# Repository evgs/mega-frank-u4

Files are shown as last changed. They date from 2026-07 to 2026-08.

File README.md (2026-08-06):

# MEGAFRANK 1.02-U4
MegaFRANK is a hardware emulation platform built around the Raspberry Pi RP2350 QFN module
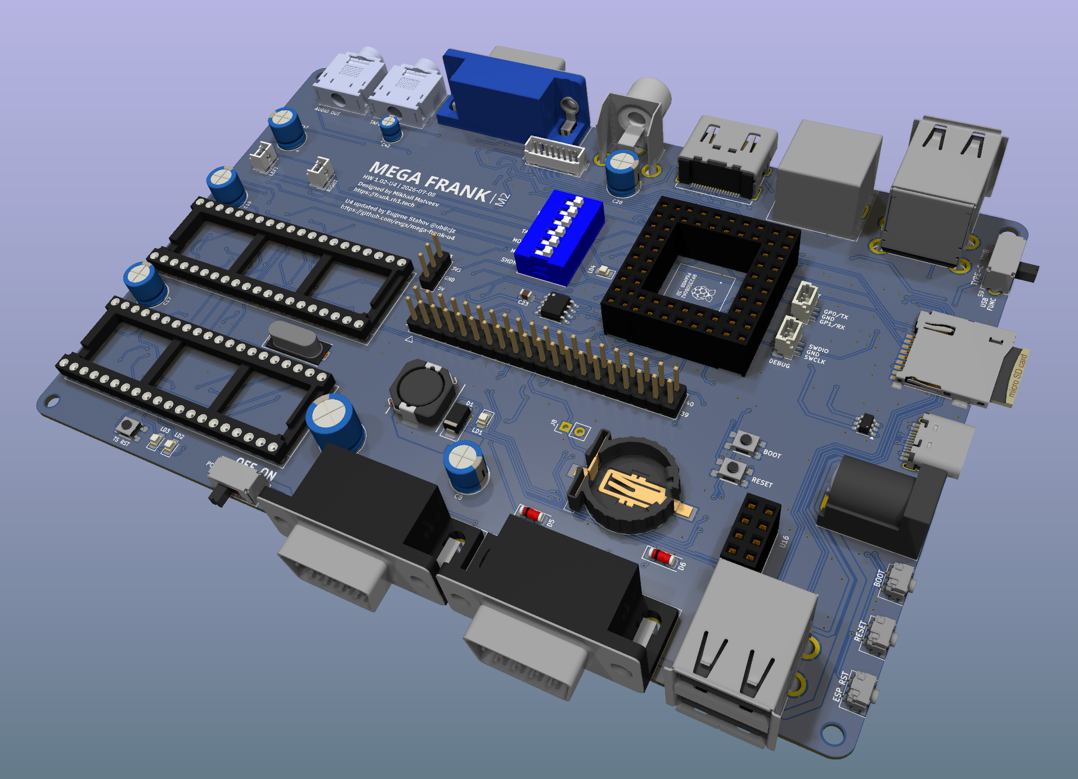
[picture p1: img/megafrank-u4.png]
board view


## DISCLAIMER 
This megafrank-u4 board is a sub-fork from https://github.com/rh1tech/frank repository originally designed by [Mikhail Matveev](https://github.com/xtremespb), [r1tech](https://github.com/rh1tech)

## Changes
- Two stacked USB-A ports were added on front board edge. 4 USB-A host ports total
- Power barrel 5mm connector was moved to right edge of the board
- ESP-RESET connected to PGPIO36 (optional, available if S11 jumper is closed) 

## DIP Switches S1 description
| Switch | Function |
| --- | --- |
| TDA | Sound path through I2S TDA (On) or PWM (Off) |
| TS | Enable TurboSound path (On) |
| TAPE | Connect TAPE IN analog input to RP2540B |
| MONO | Mono (On) of Stereo (Off) sound path |
| MPU | Enable +3V3 external pullup on GPIO0/1 (Mouse/UART port) |
| SHDN | Shutdown (On) speaker amplifier PAM8403 (outputs J13, J14) |

## TDA/TS switches useful combinations
| TDA | TS | Output selected |
| --- | --- | --- |
| off | off | RP2350 PWM |
| **ON** | off | I2S TDA1387T |
| off | **ON** | Turbosound 2xAY-3-8910 |
| **ON** | **ON** | Output Disabled |

Please read detailed docs in original project [FRANK repository](https://github.com/rh1tech/frank)

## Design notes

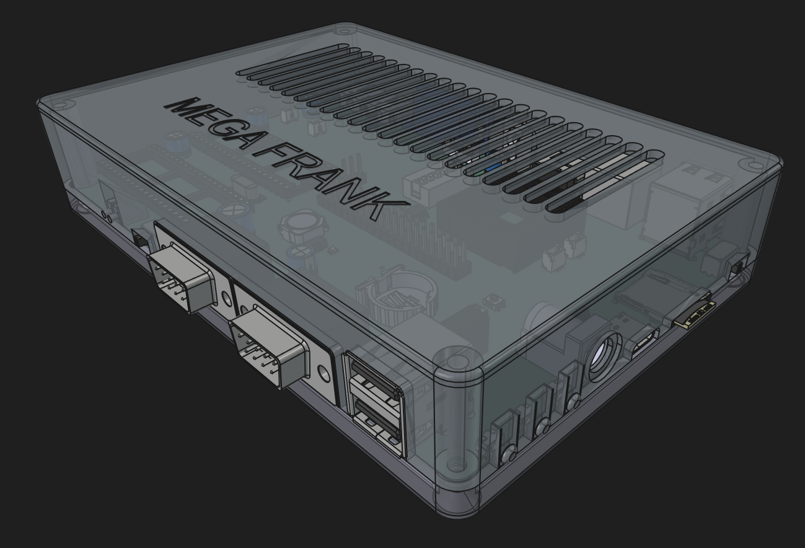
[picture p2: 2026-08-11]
case/case_preview.png

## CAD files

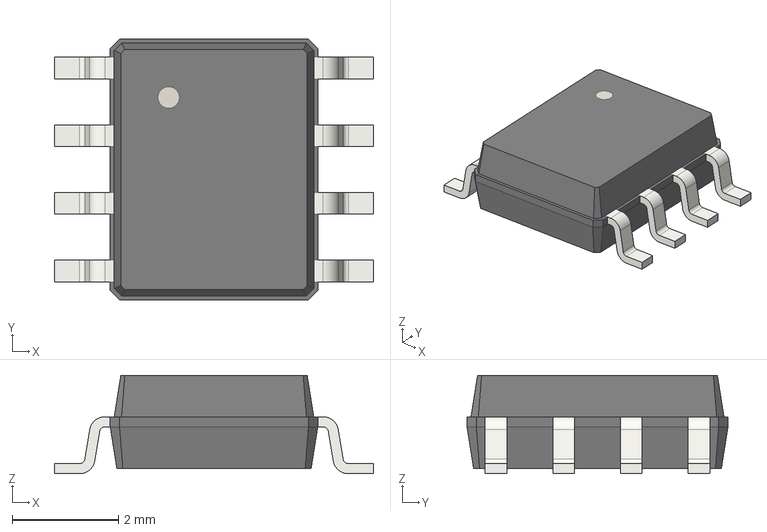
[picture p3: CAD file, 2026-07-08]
3d/SO-8.step
6.00 x 4.91 x 1.85 mm

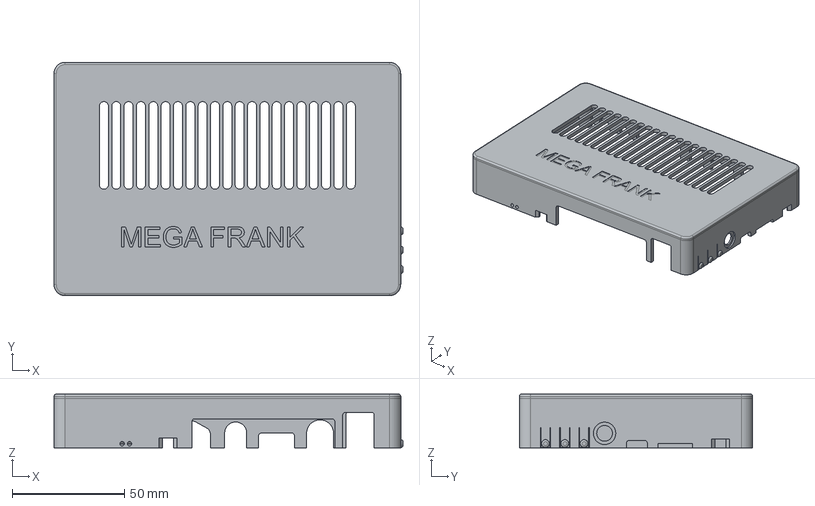
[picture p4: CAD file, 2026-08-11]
case/top-m2.5-inserts32.step
155.5 x 104.0 x 24.0 mm

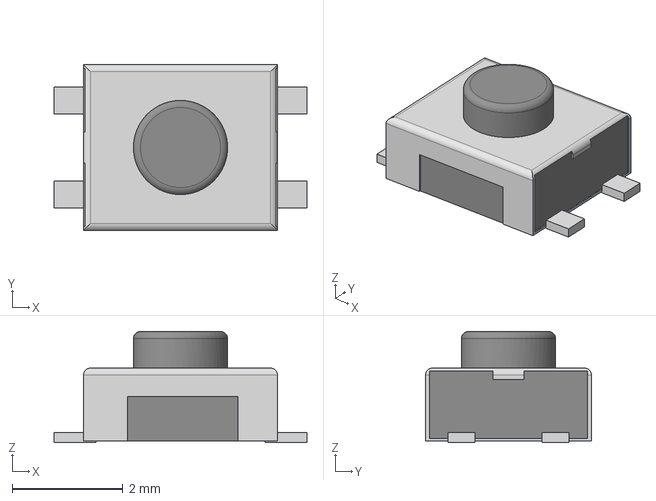
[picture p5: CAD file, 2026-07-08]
3d/Button_SMD_3x4x2mm.step
4.57 x 3.00 x 2.01 mm

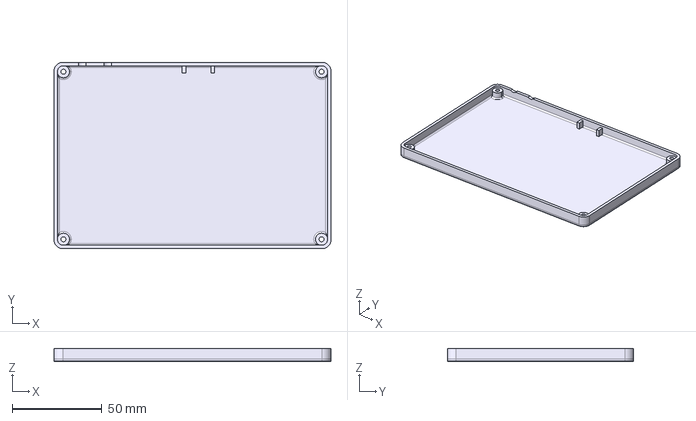
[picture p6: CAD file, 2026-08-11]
case/bottom.step
154.5 x 104.0 x 7.50 mm

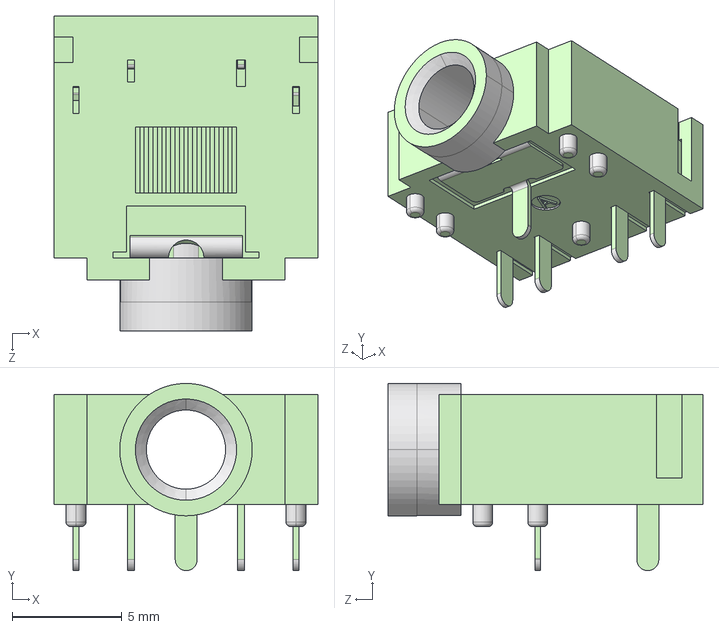
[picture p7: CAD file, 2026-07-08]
3d/AudioJack_3.5mm_SJ1-3525N_Green.step
12.0 x 8.51 x 14.3 mm

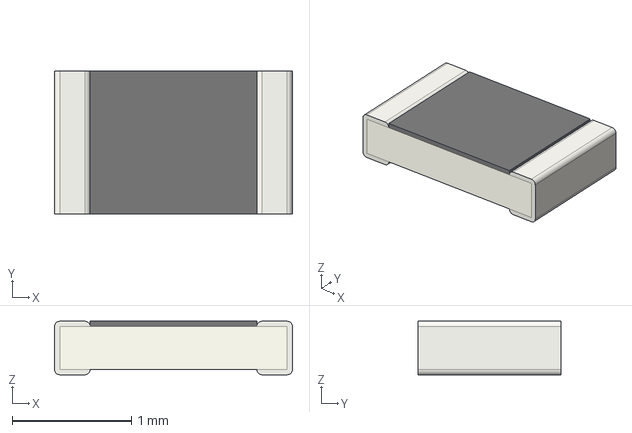
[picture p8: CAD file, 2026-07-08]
3d/R_0805_2012Metric.step
2.00 x 1.20 x 0.45 mm

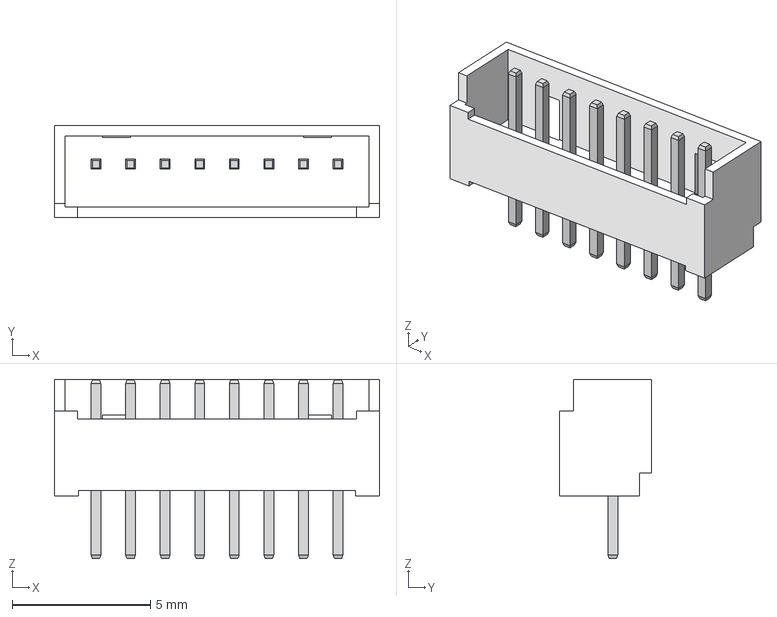
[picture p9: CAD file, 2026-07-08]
3d/JST_GH_1x08_P1.25mm.step
11.7 x 3.33 x 6.48 mm

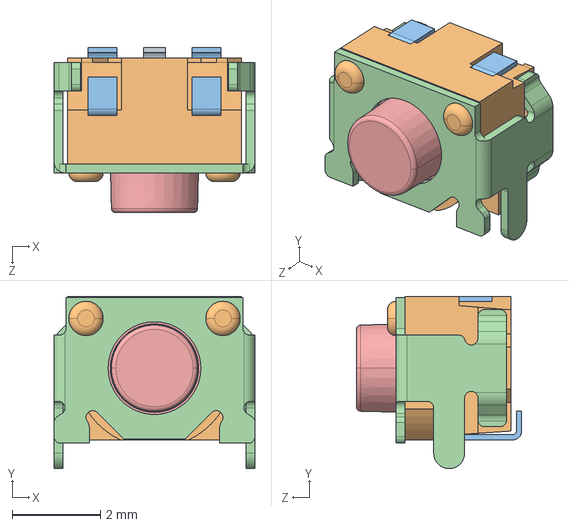
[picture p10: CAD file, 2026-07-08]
3d/Button_SMD_TS1234VW.step
4.55 x 3.90 x 3.74 mm
TS41_HOUSING
TS41-35_ACTUATOR

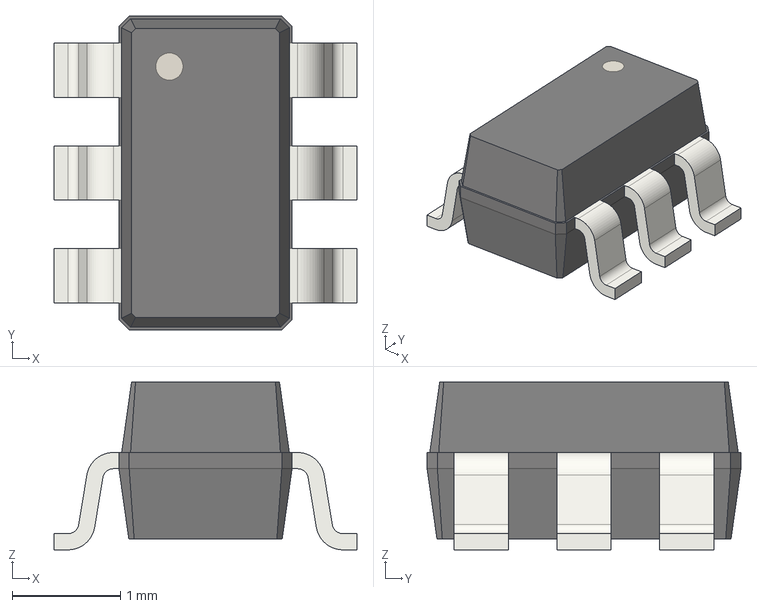
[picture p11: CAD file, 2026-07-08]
3d/SOT-23-6.step
2.80 x 2.90 x 1.55 mm

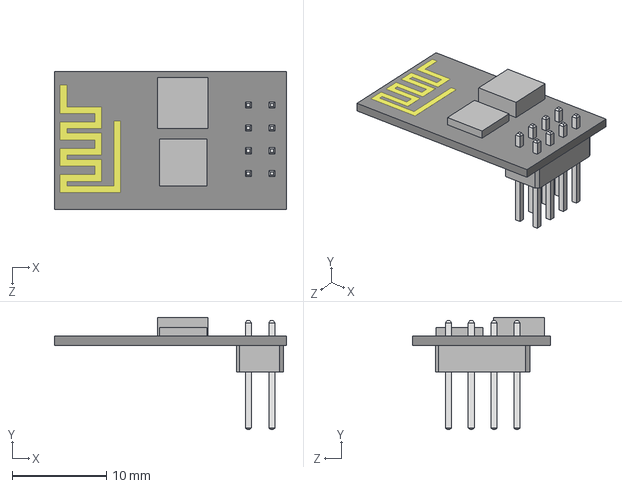
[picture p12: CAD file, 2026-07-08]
3d/ESP-01S.step
24.6 x 11.9 x 14.7 mm

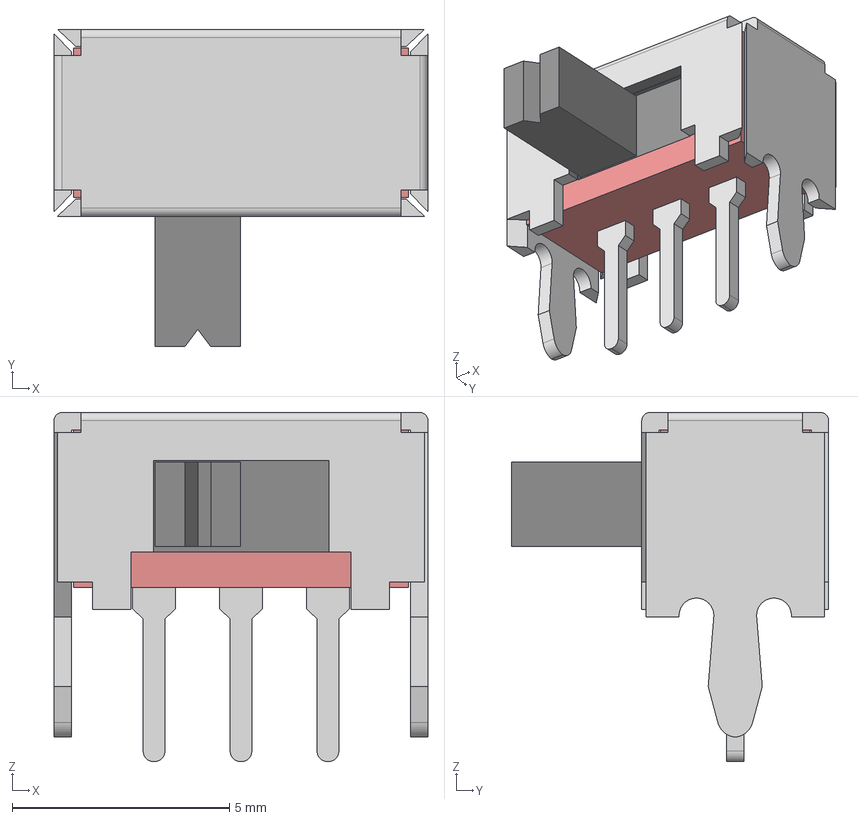
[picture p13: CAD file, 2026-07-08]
3d/Switch_Slide_SK12D07VG3NS.step
8.60 x 7.30 x 8.03 mm

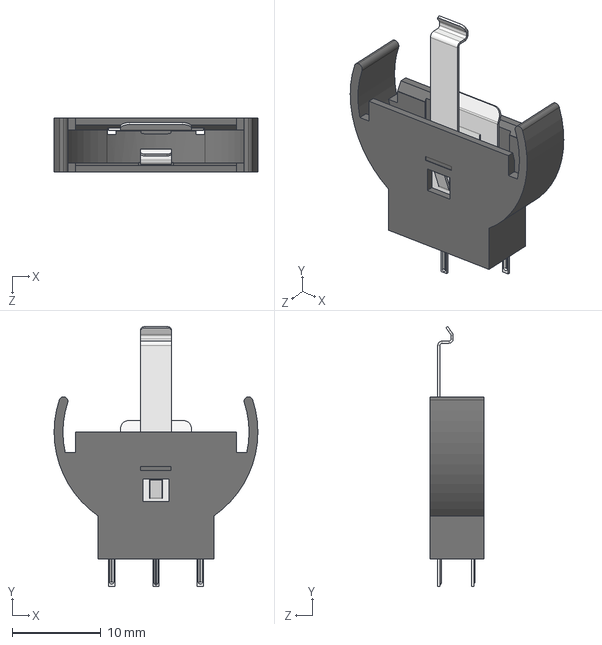
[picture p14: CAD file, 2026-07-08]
3d/Battery_CR2032.step
23.0 x 29.3 x 6.10 mm

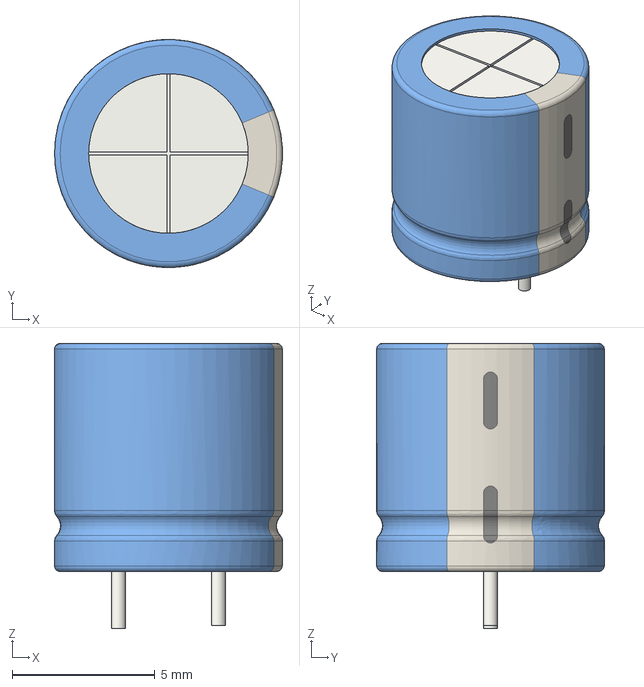
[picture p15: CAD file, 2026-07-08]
3d/C_Radial_D8.0mm_P3.50mm.step
8.00 x 8.00 x 10.0 mm

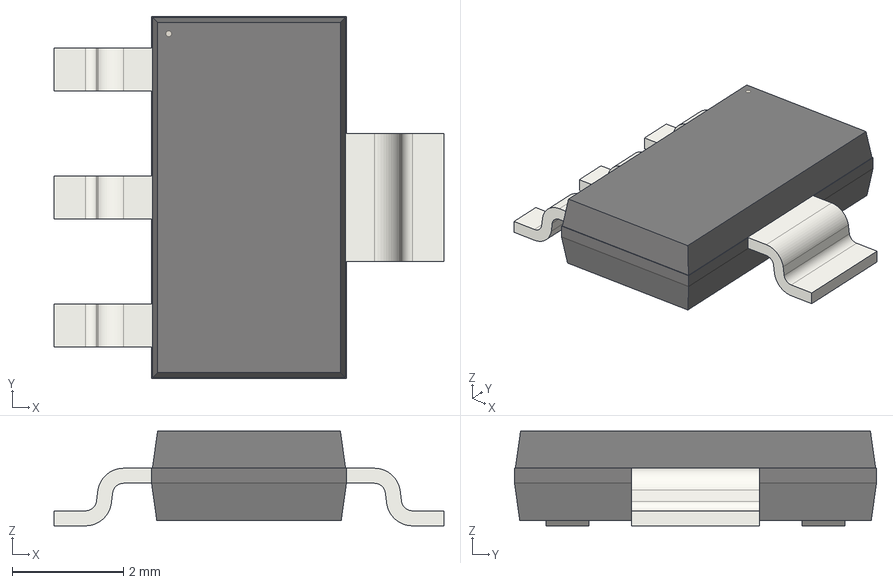
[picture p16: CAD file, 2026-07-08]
3d/SOT-223-3_TabPin2.step
7.00 x 6.50 x 1.70 mm

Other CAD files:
3d/JST_GH_1x02_P1.25mm.step
3d/AudioJack_3.5mm_SJ1-3525N_Red.step
3d/DIPSwitch_4pos_DS05.step
3d/C_0805_2012Metric.step
3d/AudioJack_3.5mm_PJ320D.step
3d/AudioJack_3.5mm_PJ320D_AudioOut.step
3d/AudioJack_3.5mm_PJ320D_TapeIn.step
3d/AudioJack_3.5mm_SJ1-3525N.step
3d/BAT-HLD-013-SMT-TR.step
3d/BarrelJack_DC-005.step
3d/BarrelJack_RCJ-012.step
3d/Battery_CR1220.step
3d/CP_Radial_D4.0mm_P1.50mm.step
3d/C_Radial_D6.3mm_P2.50mm.step
3d/Crystal_HC49-S.step
3d/DIP-40_W15.24mm_Socket.step
3d/DS01-254-S-06BE.step
3d/DS2401P+.stp
3d/DSUB-15_Female.step
3d/DSUB-9_Male_TopMount.step
3d/D_MiniMELF.step
3d/D_SMA.step
3d/D_SOD-323.step
3d/HDMI_Female.step
3d/Inductor_CDRH104RNP.step
3d/JST_SH_1x03_P1.00mm_Vertical.step
3d/JST_SH_1x04_P1.00mm_Vertical.step
3d/LED_0805.step
3d/MicroSD_SMD_Long.step
3d/MiniDIN_6pin_Female.step
3d/PinHeader_1x03_P2.54mm.step
3d/PinHeader_2x04_P2.54mm.step
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

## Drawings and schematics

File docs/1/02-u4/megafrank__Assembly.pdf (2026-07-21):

1 | 2 | 3 | 4 | 5 | 6 1 | 2 | 3 | 4 | 5 | 6 ABCD | ABCD Date: 2026-07-08

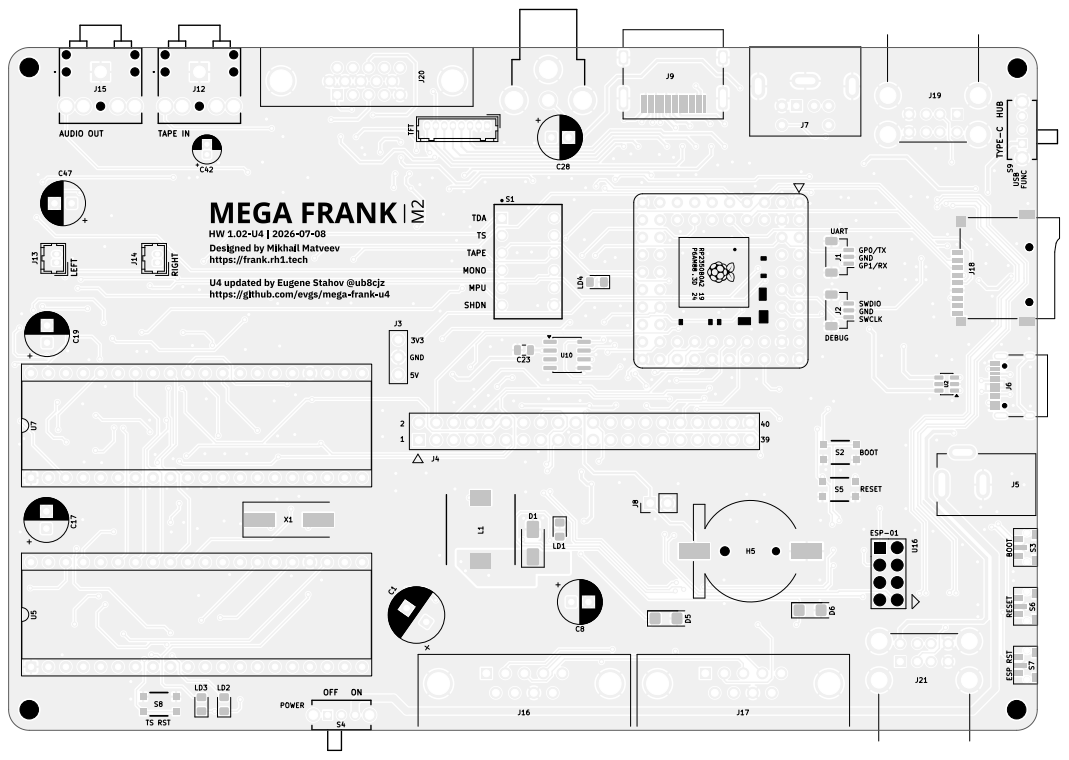
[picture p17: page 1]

Black And White TOP - Page 1/2

https://github.com/rh1tech/frank
Mikhail Matveev
Sheet: Black And White TOP
File: megafrank.kicad_pcb
Title: MEGA FRANK
KiCad E.D.A. 10.0.4

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

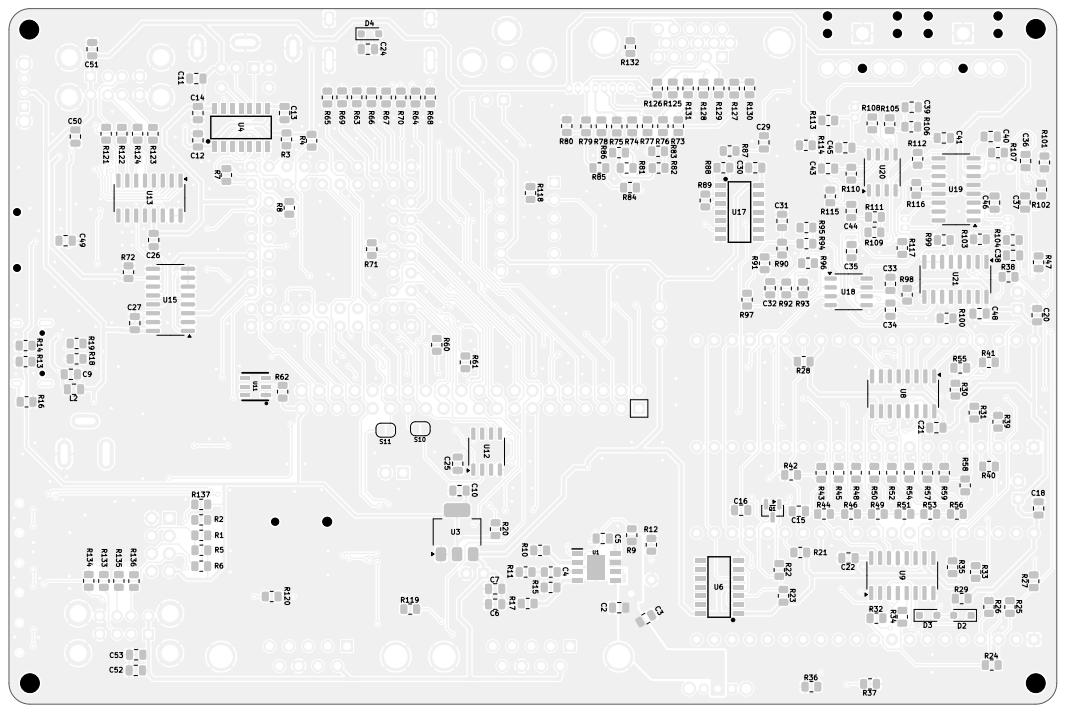
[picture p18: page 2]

https://github.com/rh1tech/frank
Mikhail Matveev
Sheet: Black And White BOT
File: megafrank.kicad_pcb
Title: MEGA FRANK

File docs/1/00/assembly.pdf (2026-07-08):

1 | 2 | 3 | 4 | 5 | 6 1 | 2 | 3 | 4 | 5 | 6 ABCD | ABCD Date: 2026-05-31

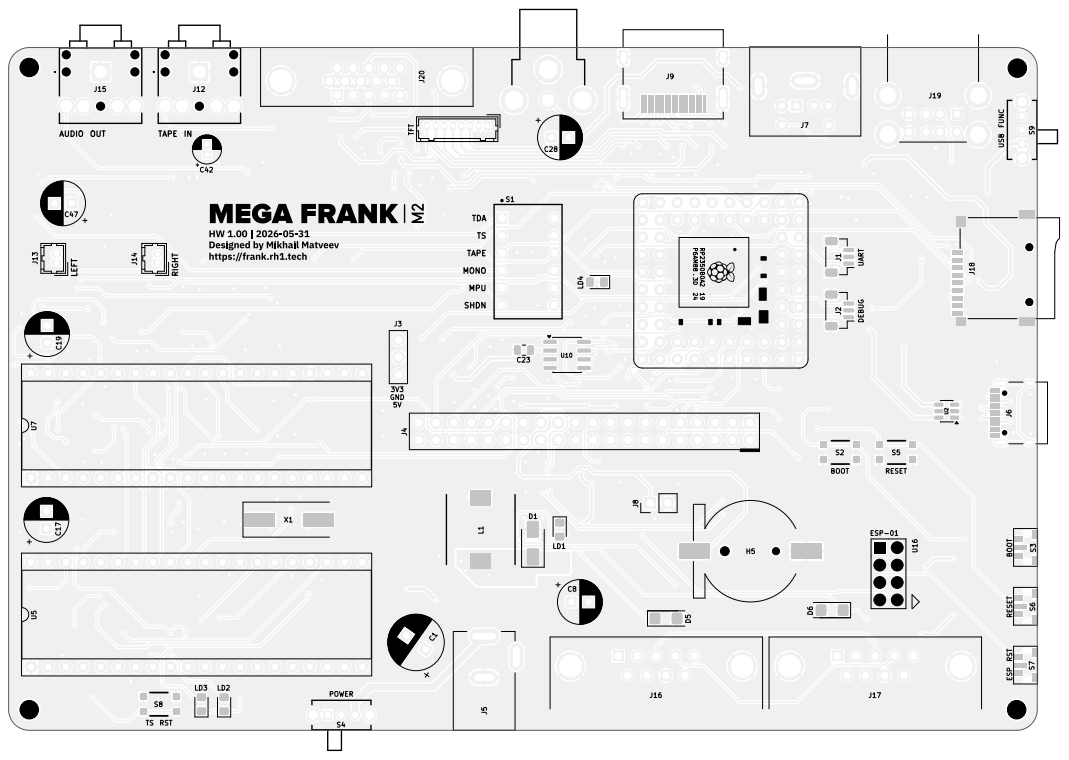
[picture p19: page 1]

Black And White TOP - Page 1/2

https://github.com/rh1tech/frank
Mikhail Matveev
Sheet: Black And White TOP
File: frank_mega.kicad_pcb
Title: MEGA FRANK
KiCad E.D.A. 10.0.1

1 | 2 | 3 | 4 | 5 | 6 1 | 2 | 3 | 4 | 5 | 6 ABCD | ABCD Date: 2026-05-31
U1 C24

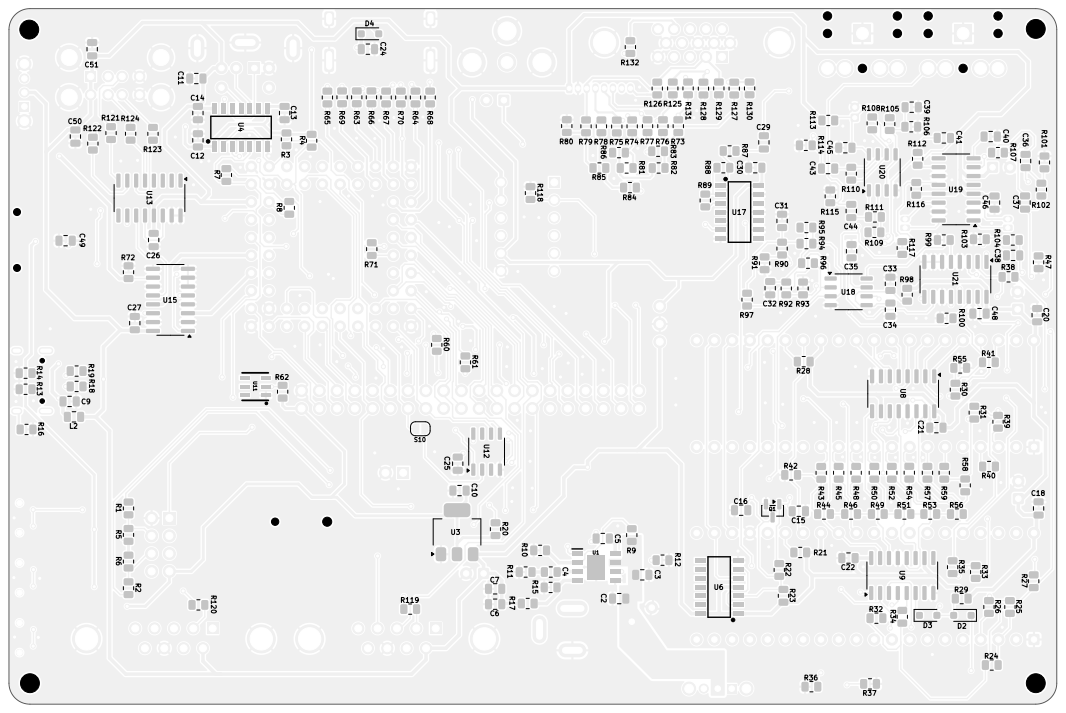
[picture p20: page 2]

https://github.com/rh1tech/frank
Mikhail Matveev
Sheet: Black And White BOT
File: frank_mega.kicad_pcb
Title: MEGA FRANK
KiCad E.D.A. 10.0.1

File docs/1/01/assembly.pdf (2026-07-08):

1 | 2 | 3 | 4 | 5 | 6 1 | 2 | 3 | 4 | 5 | 6 ABCD | ABCD Date: 2026-06-04

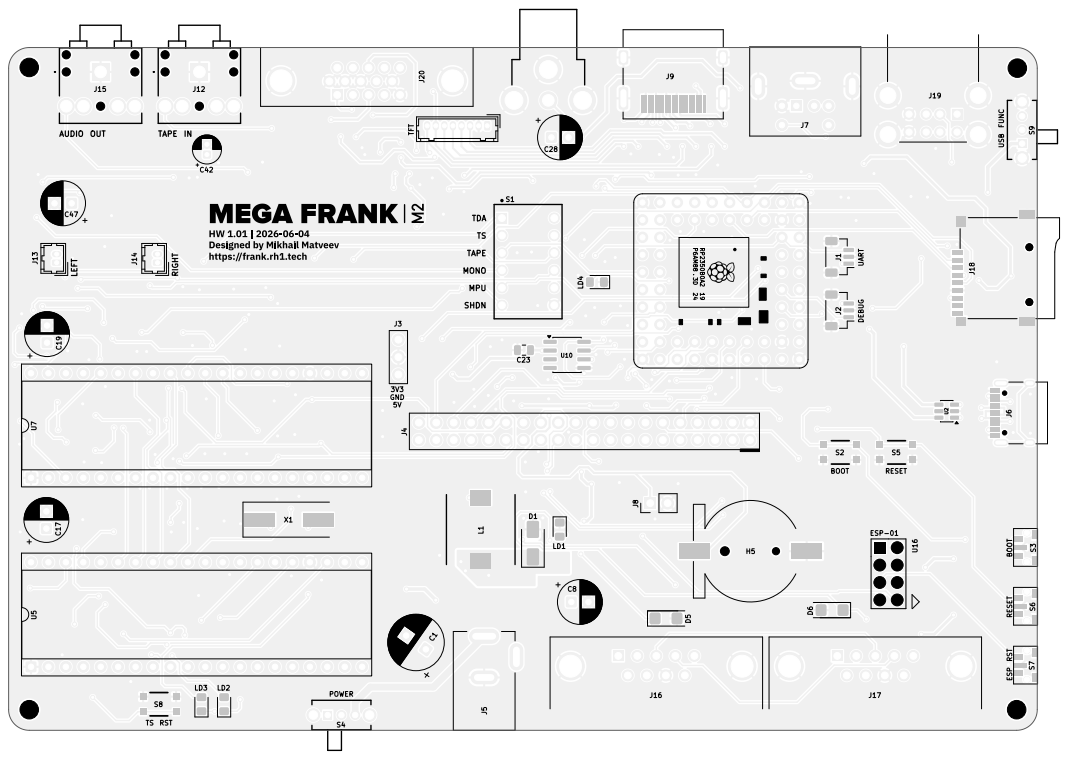
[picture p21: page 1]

Black And White TOP - Page 1/2

https://github.com/rh1tech/frank
Mikhail Matveev
Sheet: Black And White TOP
File: frank_mega.kicad_pcb
Title: MEGA FRANK
KiCad E.D.A. 10.0.1

1 | 2 | 3 | 4 | 5 | 6 1 | 2 | 3 | 4 | 5 | 6 ABCD | ABCD Date: 2026-06-04
U1 C24

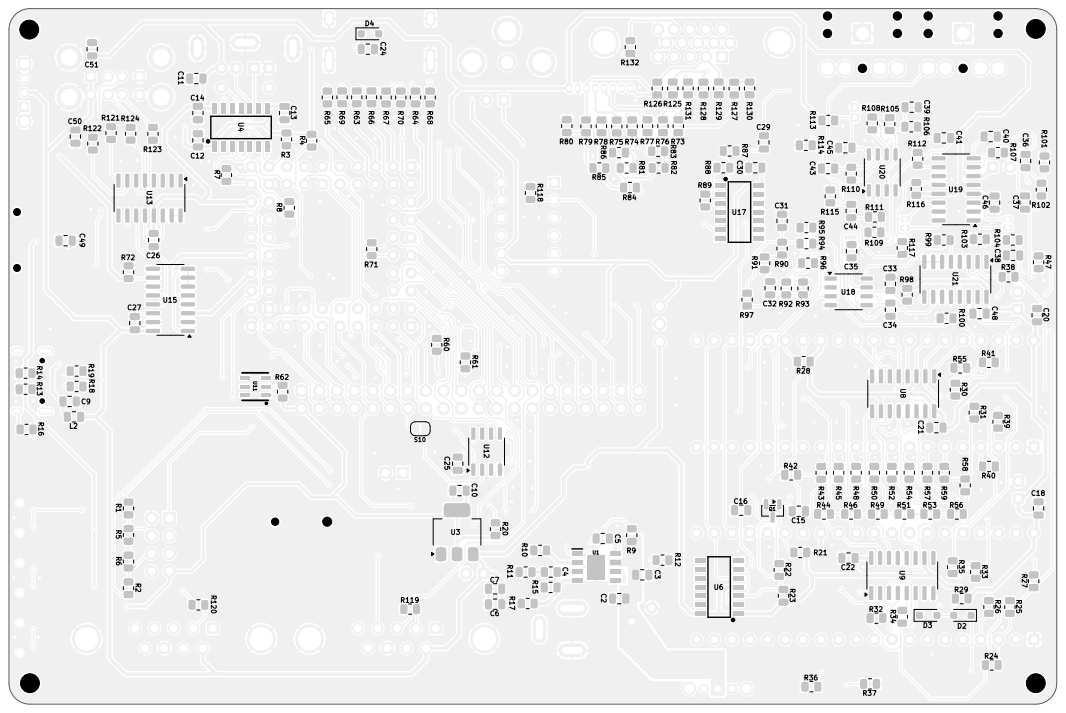
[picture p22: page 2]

https://github.com/rh1tech/frank
Mikhail Matveev
Sheet: Black And White BOT
File: frank_mega.kicad_pcb
Title: MEGA FRANK
KiCad E.D.A. 10.0.1

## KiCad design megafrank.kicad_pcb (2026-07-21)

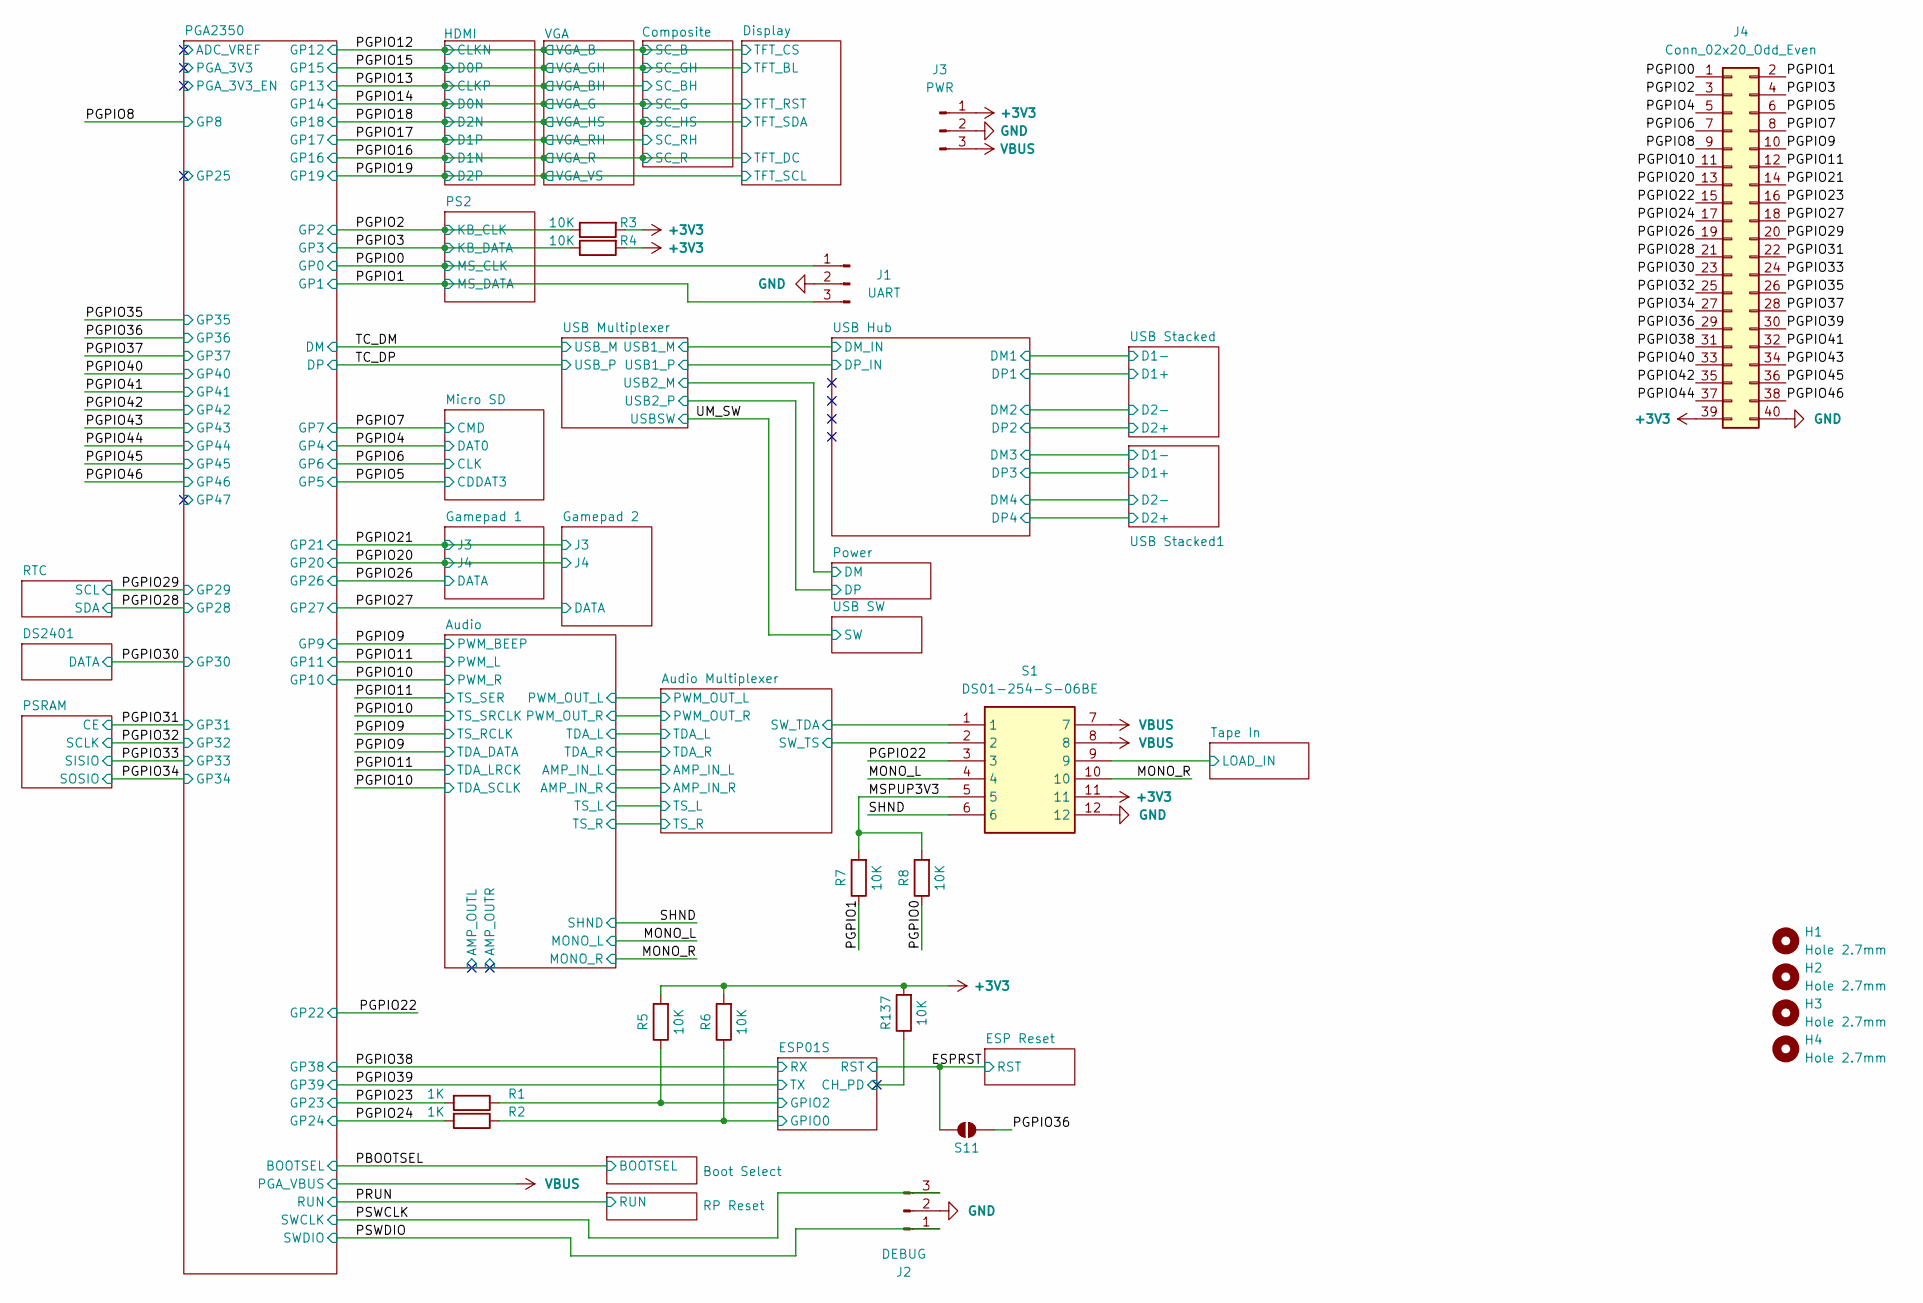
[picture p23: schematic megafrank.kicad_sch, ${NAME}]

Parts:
H1, H2, H3, H4: Hole 2.7mm; MountingHole_2.7mm
J1: UART; JST_SH_1x03_P1.00mm_Vertical
J2: DEBUG; JST_SH_1x03_P1.00mm_Vertical
J3: PWR; PinHeader_1x03_P2.54mm
J4: Conn_02x20_Odd_Even; PinHeader_2x20_P2.54mm_Vertical
R1, R2: 1K; R_0805_2012Metric
R3, R4, R5, R6, R7, R8, R137: 10K; R_0805_2012Metric
S1: DS01-254-S-06BE; Manufacturer_Part_Number DS01-254-S-06BE
S11: PICO-ESP-RESET; SolderJumper-2_P1.3mm_Open_RoundedPad1.0x1.5mm

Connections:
+3V3: J3.1, J4.39, R3.2, R4.2, R5.2, R6.2, R137.2, S1.11; also elsewhere on the board
/Audio Multiplexer/SW_TDA: S1.1; also elsewhere on the board
/Audio Multiplexer/SW_TS: S1.2; also elsewhere on the board
/ESP01S/CH_PD: R137.1; also elsewhere on the board
/ESP01S/GPIO0: R2.1, R6.1; also elsewhere on the board
/ESP01S/GPIO2: R1.1, R5.1; also elsewhere on the board
/ESPRST: S11.1 (A); also elsewhere on the board
/MONO_L: S1.4; also elsewhere on the board
/MONO_R: S1.10; also elsewhere on the board
/MSPUP3V3: R7.2, R8.2, S1.5
/PGPIO0: J1.1, J4.1, R8.1; also elsewhere on the board
/PGPIO1: J1.3, J4.2, R7.1; also elsewhere on the board
/PGPIO2: J4.3, R3.1; also elsewhere on the board
/PGPIO3: J4.4, R4.1; also elsewhere on the board
/PGPIO4: J4.5; also elsewhere on the board
/PGPIO5: J4.6; also elsewhere on the board
/PGPIO6: J4.7; also elsewhere on the board
/PGPIO7: J4.8; also elsewhere on the board
/PGPIO8: J4.9; also elsewhere on the board
/PGPIO9: J4.10; also elsewhere on the board
/PGPIO10: J4.11; also elsewhere on the board
/PGPIO11: J4.12; also elsewhere on the board
/PGPIO20: J4.13; also elsewhere on the board
/PGPIO21: J4.14; also elsewhere on the board
/PGPIO22: J4.15, S1.3; also elsewhere on the board
/PGPIO23: J4.16, R1.2; also elsewhere on the board
/PGPIO24: J4.17, R2.2; also elsewhere on the board
/PGPIO26: J4.19; also elsewhere on the board
/PGPIO27: J4.18; also elsewhere on the board
/PGPIO28: J4.21; also elsewhere on the board
/PGPIO29: J4.20; also elsewhere on the board
/PGPIO30: J4.23; also elsewhere on the board
/PGPIO31: J4.22; also elsewhere on the board
/PGPIO32: J4.25; also elsewhere on the board
/PGPIO33: J4.24; also elsewhere on the board
/PGPIO34: J4.27; also elsewhere on the board
/PGPIO35: J4.26; also elsewhere on the board
/PGPIO36: J4.29, S11.2 (B); also elsewhere on the board
/PGPIO37: J4.28; also elsewhere on the board
/PGPIO38: J4.31; also elsewhere on the board
/PGPIO39: J4.30; also elsewhere on the board
/PGPIO40: J4.33; also elsewhere on the board
/PGPIO41: J4.32; also elsewhere on the board
/PGPIO42: J4.35; also elsewhere on the board
/PGPIO43: J4.34; also elsewhere on the board
/PGPIO44: J4.37; also elsewhere on the board
/PGPIO45: J4.36; also elsewhere on the board
/PGPIO46: J4.38; also elsewhere on the board
/PSWCLK: J2.3; also elsewhere on the board
/PSWDIO: J2.1; also elsewhere on the board
/SHND: S1.6; also elsewhere on the board
/Tape In/LOAD_IN: S1.9; also elsewhere on the board
GND: J1.2, J2.2, J3.2, J4.40, S1.12; also elsewhere on the board
VBUS: J3.3, S1.7, S1.8; also elsewhere on the board

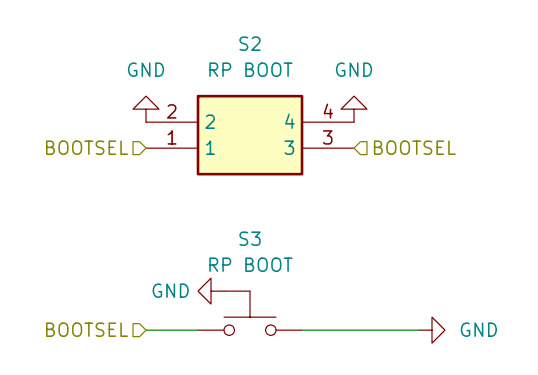
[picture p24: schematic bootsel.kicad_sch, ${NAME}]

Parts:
S2: RP BOOT; Button_SMD_3x4x2mm; Mouser Part Number 611-KMR221G-LFS
S3: RP BOOT; Button_SMD_TS1234VW

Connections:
/PBOOTSEL: S2.1, S2.3, S3.1; also elsewhere on the board
GND: S2.2, S2.4, S3.2, S3.3 (GND); also elsewhere on the board

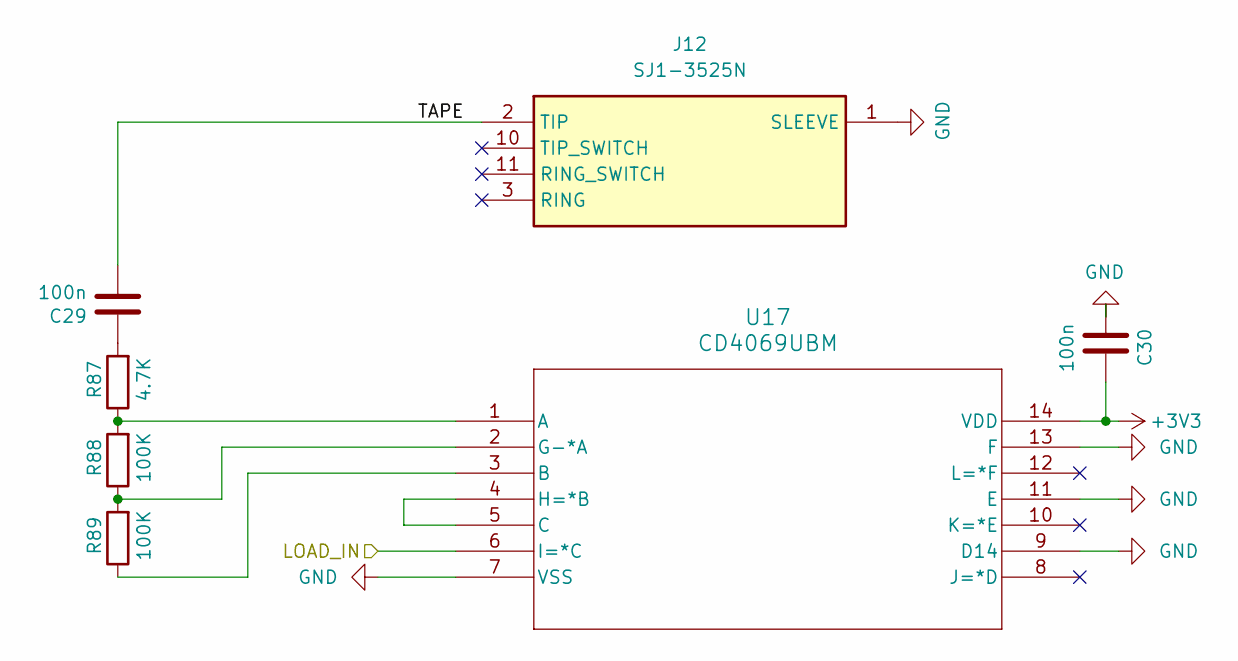
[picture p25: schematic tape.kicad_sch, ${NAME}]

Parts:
C29, C30: 100n; C_0805_2012Metric
J12: SJ1-3525N; AudioJack_3.5mm_SJ1-3525N; Mouser Part Number 490-SJ1-3525N
R87: 4.7K; R_0805_2012Metric
R88, R89: 100K; R_0805_2012Metric
U17: CD4069UBM; SOIC-14_P1.27mm

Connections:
+3V3: C30.1, U17.14 (VDD); also elsewhere on the board
/Tape In/LOAD_IN: U17.6 (I=*C); also elsewhere on the board
/Tape In/TAPE: C29.2, J12.2 (TIP)
GND: C30.2, J12.1 (SLEEVE), U17.7 (VSS), U17.9 (D14), U17.11 (E), U17.13 (F); also elsewhere on the board
unnamed: C29.1, R87.2
unnamed: R87.1, R88.2, U17.1 (A)
unnamed: R89.1, U17.3 (B)
unnamed: U17.4 (H=*B), U17.5 (C)
unnamed: R88.1, R89.2, U17.2 (G-*A)

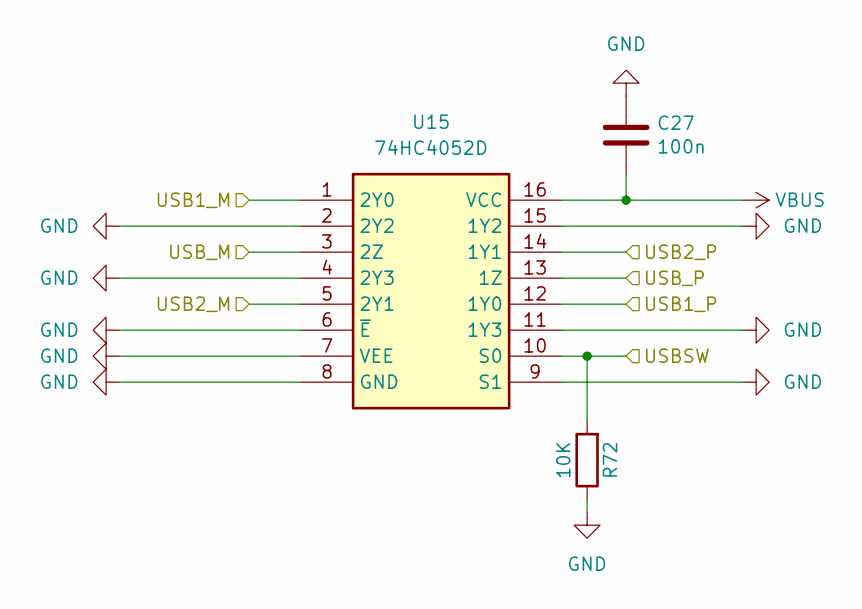
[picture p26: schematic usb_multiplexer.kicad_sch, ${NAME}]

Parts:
C27: 100n; C_0805_2012Metric
R72: 10K; R_0805_2012Metric
U15: 74HC4052D; SOP-16_P1.27mm; Mouser Part Number 771-74HC4052D-T

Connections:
/Power/DM: U15.5 (2Y1); also elsewhere on the board
/Power/DP: U15.14 (1Y1); also elsewhere on the board
/TC_DM: U15.3 (2Z); also elsewhere on the board
/TC_DP: U15.13 (1Z); also elsewhere on the board
/UM_SW: R72.2, U15.10 (S0); also elsewhere on the board
/USB Hub/DM_IN: U15.1 (2Y0); also elsewhere on the board
/USB Hub/DP_IN: U15.12 (1Y0); also elsewhere on the board
GND: C27.1, R72.1, U15.2 (2Y2), U15.4 (2Y3), U15.6 (~E), U15.7 (VEE), U15.8 (GND), U15.9 (S1), U15.11 (1Y3), U15.15 (1Y2); also elsewhere on the board
VBUS: C27.2, U15.16 (VCC); also elsewhere on the board

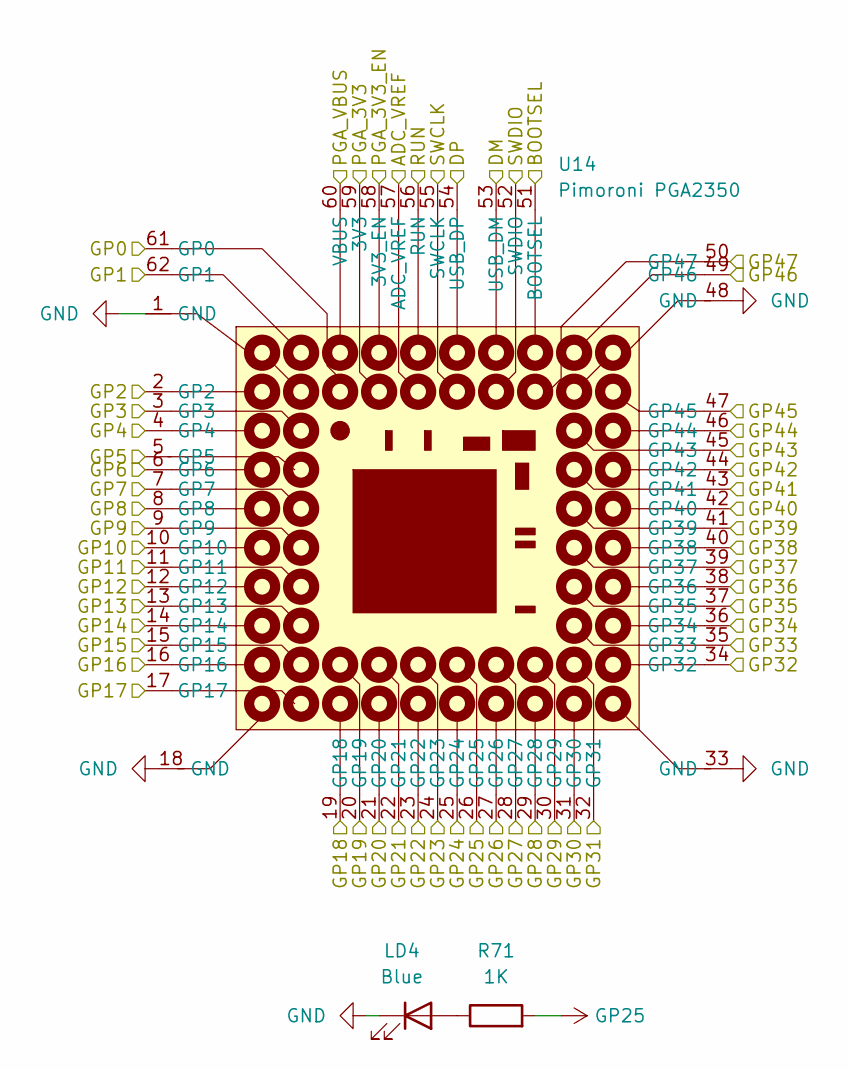
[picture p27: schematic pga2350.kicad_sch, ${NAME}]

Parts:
LD4: Blue; LED_0805
R71: 1K; R_0805_2012Metric
U14: Pimoroni PGA2350; PGA2350

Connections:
/PBOOTSEL: U14.51 (BOOTSEL); also elsewhere on the board
/PGA2350/ADC_VREF: U14.57 (ADC_VREF)
/PGA2350/GP47: U14.50 (GP47)
/PGA2350/PGA_3V3: U14.59 (3V3)
/PGA2350/PGA_3V3_EN: U14.58 (3V3_EN)
/PGPIO0: U14.61 (GP0); also elsewhere on the board
/PGPIO1: U14.62 (GP1); also elsewhere on the board
/PGPIO2: U14.2 (GP2); also elsewhere on the board
/PGPIO3: U14.3 (GP3); also elsewhere on the board
/PGPIO4: U14.4 (GP4); also elsewhere on the board
/PGPIO5: U14.5 (GP5); also elsewhere on the board
/PGPIO6: U14.6 (GP6); also elsewhere on the board
/PGPIO7: U14.7 (GP7); also elsewhere on the board
/PGPIO8: U14.8 (GP8); also elsewhere on the board
/PGPIO9: U14.9 (GP9); also elsewhere on the board
/PGPIO10: U14.10 (GP10); also elsewhere on the board
/PGPIO11: U14.11 (GP11); also elsewhere on the board
/PGPIO12: U14.12 (GP12); also elsewhere on the board
/PGPIO13: U14.13 (GP13); also elsewhere on the board
/PGPIO14: U14.14 (GP14); also elsewhere on the board
/PGPIO15: U14.15 (GP15); also elsewhere on the board
/PGPIO16: U14.16 (GP16); also elsewhere on the board
/PGPIO17: U14.17 (GP17); also elsewhere on the board
/PGPIO18: U14.19 (GP18); also elsewhere on the board
/PGPIO19: U14.20 (GP19); also elsewhere on the board
/PGPIO20: U14.21 (GP20); also elsewhere on the board
/PGPIO21: U14.22 (GP21); also elsewhere on the board
/PGPIO22: U14.23 (GP22); also elsewhere on the board
/PGPIO23: U14.24 (GP23); also elsewhere on the board
/PGPIO24: U14.25 (GP24); also elsewhere on the board
/PGPIO26: U14.27 (GP26); also elsewhere on the board
/PGPIO27: U14.28 (GP27); also elsewhere on the board
/PGPIO28: U14.29 (GP28); also elsewhere on the board
/PGPIO29: U14.30 (GP29); also elsewhere on the board
/PGPIO30: U14.31 (GP30); also elsewhere on the board
/PGPIO31: U14.32 (GP31); also elsewhere on the board
/PGPIO32: U14.34 (GP32); also elsewhere on the board
/PGPIO33: U14.35 (GP33); also elsewhere on the board
/PGPIO34: U14.36 (GP34); also elsewhere on the board
/PGPIO35: U14.37 (GP35); also elsewhere on the board
/PGPIO36: U14.38 (GP36); also elsewhere on the board
/PGPIO37: U14.39 (GP37); also elsewhere on the board
/PGPIO38: U14.40 (GP38); also elsewhere on the board
/PGPIO39: U14.41 (GP39); also elsewhere on the board
/PGPIO40: U14.42 (GP40); also elsewhere on the board
/PGPIO41: U14.43 (GP41); also elsewhere on the board
/PGPIO42: U14.44 (GP42); also elsewhere on the board
/PGPIO43: U14.45 (GP43); also elsewhere on the board
/PGPIO44: U14.46 (GP44); also elsewhere on the board
/PGPIO45: U14.47 (GP45); also elsewhere on the board
/PGPIO46: U14.49 (GP46); also elsewhere on the board
/PRUN: U14.56 (RUN); also elsewhere on the board
/PSWCLK: U14.55 (SWCLK); also elsewhere on the board
/PSWDIO: U14.52 (SWDIO); also elsewhere on the board
/TC_DM: U14.53 (USB_DM); also elsewhere on the board
/TC_DP: U14.54 (USB_DP); also elsewhere on the board
GND: LD4.1 (K), U14.1 (GND), U14.18 (GND), U14.33 (GND), U14.48 (GND); also elsewhere on the board
GP25: R71.2, U14.26 (GP25)
unnamed: LD4.2 (A), R71.1
VBUS: U14.60 (VBUS); also elsewhere on the board

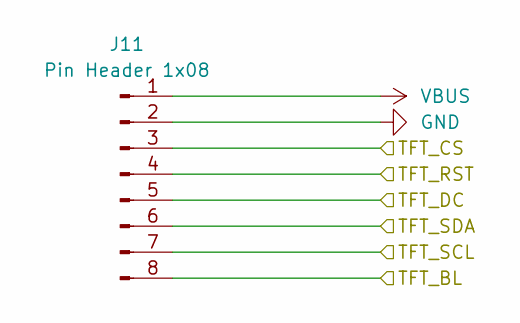
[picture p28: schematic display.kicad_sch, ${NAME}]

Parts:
J11: Pin Header 1x08; JST_GH_1x08_P1.25mm

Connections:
/PGPIO12: J11.3; also elsewhere on the board
/PGPIO14: J11.4; also elsewhere on the board
/PGPIO15: J11.8; also elsewhere on the board
/PGPIO16: J11.5; also elsewhere on the board
/PGPIO18: J11.6; also elsewhere on the board
/PGPIO19: J11.7; also elsewhere on the board
GND: J11.2; also elsewhere on the board
VBUS: J11.1; also elsewhere on the board

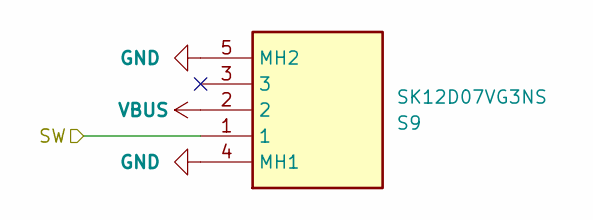
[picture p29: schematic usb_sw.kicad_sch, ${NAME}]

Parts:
S9: SK12D07VG3NS; Switch_Slide_SK12D07VG3NS; Mouser Part Number 611-SK12D07VG3NS

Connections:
/UM_SW: S9.1; also elsewhere on the board
GND: S9.4 (MH1), S9.5 (MH2); also elsewhere on the board
VBUS: S9.2; also elsewhere on the board

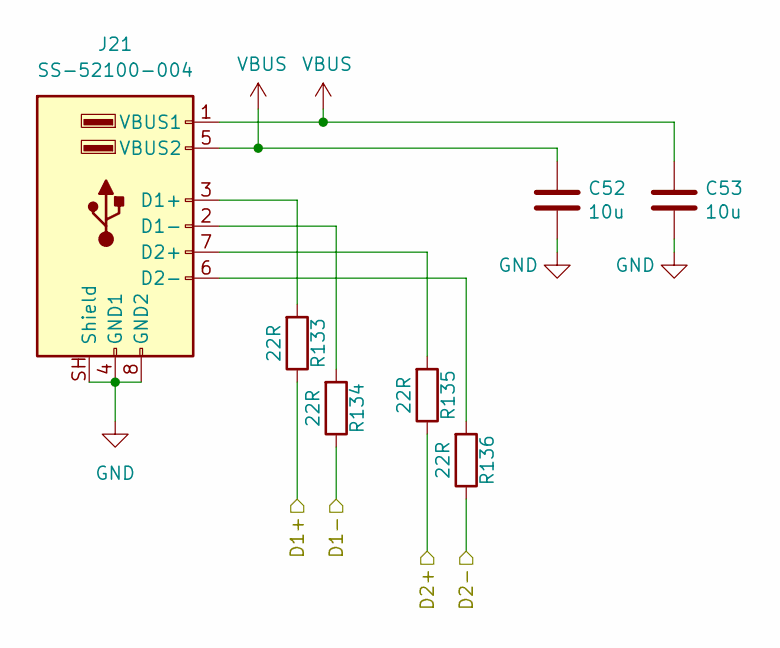
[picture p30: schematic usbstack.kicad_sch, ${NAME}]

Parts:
C52, C53: 10u; C_0805_2012Metric
J21: SS-52100-004; USB_A_Stacked
R133, R134, R135, R136: 22R; R_0805_2012Metric

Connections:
/USB Hub/DM3: R134.1; also elsewhere on the board
/USB Hub/DM4: R136.1; also elsewhere on the board
/USB Hub/DP3: R133.1; also elsewhere on the board
/USB Hub/DP4: R135.1; also elsewhere on the board
GND: C52.2, C53.2, J21.4 (GND1), J21.8 (GND2), J21.SH (Shield); also elsewhere on the board
unnamed: J21.3 (D1+), R133.2
unnamed: J21.2 (D1-), R134.2
unnamed: J21.7 (D2+), R135.2
unnamed: J21.6 (D2-), R136.2
VBUS: C52.1, C53.1, J21.1 (VBUS1), J21.5 (VBUS2); also elsewhere on the board

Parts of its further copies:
C50, C51: 10u; C_0805_2012Metric
J19: SS-52100-004; USB_A_Stacked
R121, R122, R123, R124: 22R; R_0805_2012Metric

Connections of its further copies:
/USB Hub/DM1: R122.1; also elsewhere on the board
/USB Hub/DM2: R124.1; also elsewhere on the board
/USB Hub/DP1: R121.1; also elsewhere on the board
/USB Hub/DP2: R123.1; also elsewhere on the board
GND: C50.2, C51.2, J19.4 (GND1), J19.8 (GND2), J19.SH (Shield); also elsewhere on the board
unnamed: J19.3 (D1+), R121.2
unnamed: J19.2 (D1-), R122.2
unnamed: J19.7 (D2+), R123.2
unnamed: J19.6 (D2-), R124.2
VBUS: C50.1, C51.1, J19.1 (VBUS1), J19.5 (VBUS2); also elsewhere on the board

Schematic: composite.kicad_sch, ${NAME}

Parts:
C28: 220u; C_Radial_D6.3mm_P2.50mm
J10: RCA-103; BarrelJack_RCJ-012
R73: 750R; R_0805_2012Metric
R74, R75, R76, R77, R78, R79: 270R; R_0805_2012Metric
R80: 300R; R_0805_2012Metric
R81, R82, R83, R84, R85: 150R; R_0805_2012Metric
R86: 51R; R_0805_2012Metric

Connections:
/Composite/CVBS: C28.2, J10.1
/PGPIO12: R79.1; also elsewhere on the board
/PGPIO13: R78.1; also elsewhere on the board
/PGPIO14: R75.1; also elsewhere on the board
/PGPIO15: R74.1; also elsewhere on the board
/PGPIO16: R77.1; also elsewhere on the board
/PGPIO17: R76.1; also elsewhere on the board
/PGPIO18: R73.1; also elsewhere on the board
GND: J10.2, R80.1; also elsewhere on the board
unnamed: C28.1, R86.2
unnamed: R73.2, R74.2, R81.2, R86.1
unnamed: R75.2, R81.1, R82.2
unnamed: R76.2, R82.1, R83.2
unnamed: R77.2, R83.1, R84.2
unnamed: R78.2, R84.1, R85.2
unnamed: R79.2, R80.2, R85.1

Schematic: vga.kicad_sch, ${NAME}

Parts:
J20: VGA; DSUB-15_Female
R125, R126, R127: 330R; R_0805_2012Metric
R128, R129, R130: 1K; R_0805_2012Metric
R131, R132: 100R; R_0805_2012Metric

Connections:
/PGPIO12: R130.1; also elsewhere on the board
/PGPIO13: R127.1; also elsewhere on the board
/PGPIO14: R129.1; also elsewhere on the board
/PGPIO15: R126.1; also elsewhere on the board
/PGPIO16: R128.1; also elsewhere on the board
/PGPIO17: R125.1; also elsewhere on the board
/PGPIO18: R131.2; also elsewhere on the board
/PGPIO19: R132.2; also elsewhere on the board
GND: J20.0, J20.5, J20.6, J20.7, J20.8, J20.10; also elsewhere on the board
unnamed: J20.1, R125.2, R128.2
unnamed: J20.2, R126.2, R129.2
unnamed: J20.3, R127.2, R130.2
unnamed: J20.13, R131.1
unnamed: J20.14, R132.1

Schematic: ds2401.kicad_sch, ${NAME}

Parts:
R62: 4.7K; R_0805_2012Metric
U11: DS2401P+; TSOC-6; Mouser Part Number 700-DS2401P

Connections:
+3V3: R62.1; also elsewhere on the board
/PGPIO30: R62.2, U11.2 (DATA); also elsewhere on the board
GND: U11.1 (GND); also elsewhere on the board

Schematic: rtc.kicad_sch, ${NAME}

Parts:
C23: 100n; C_0805_2012Metric
H5: Battery_CR1220; Manufacturer_Part_Number 1174
J8: BAT 3V; PinHeader_1x02_P2.54mm_Vertical
R60, R61: 4.7K; R_0805_2012Metric
U10: DS3231MZ; SOIC-8_3.9x4.9mm_P1.27mm

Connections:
+3V3: C23.1, R60.2, R61.2, U10.2 (VCC); also elsewhere on the board
/PGPIO28: R61.1, U10.7 (SDA); also elsewhere on the board
/PGPIO29: R60.1, U10.8 (SCL); also elsewhere on the board
GND: C23.2, H5.2 (-), J8.2, U10.5 (GND); also elsewhere on the board
unnamed: H5.1 (+), J8.1, U10.6 (VBAT)

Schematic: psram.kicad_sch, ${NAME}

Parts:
C25: 100n; C_0805_2012Metric
S10: PSRAM On; SolderJumper-2_P1.3mm_Open_RoundedPad1.0x1.5mm
U12: ESP-PSRAM64; SO-8

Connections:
+3V3: C25.1, U12.8 (VCC); also elsewhere on the board
/PGPIO31: U12.1 (~CE); also elsewhere on the board
/PGPIO32: U12.6 (SCLK); also elsewhere on the board
/PGPIO33: U12.5 (SI/SIO); also elsewhere on the board
/PGPIO34: S10.2 (B); also elsewhere on the board
GND: C25.2, U12.4 (VSS); also elsewhere on the board
unnamed: S10.1 (A), U12.2 (SO/SIO)

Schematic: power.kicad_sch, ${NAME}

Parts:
C1: 680u; C_Radial_D8.0mm_P3.50mm
C2, C7, C10: 10u; C_0805_2012Metric
C3, C5, C6, C9: 100n; C_0805_2012Metric
C4: 150pF; R_0805_2012Metric
C8: 220u; C_Radial_D6.3mm_P2.50mm
D1: 1N5822; D_SMA
J5: DC-005-5A-2.0; BarrelJack_DC-005; PARTREV A0
J6: USB4215-03-A; USB_C_Receptacle
L1: 22uH; Inductor_CDRH104RNP
L2: 330R; C_0805_2012Metric
LD1: Green; LED_0805
R9, R11, R12: 100K; R_0805_2012Metric
R10: 24K; R_0805_2012Metric
R13, R14: 5.1K; R_0805_2012Metric
R15: 8.2K; R_0805_2012Metric
R16: 1M; R_0805_2012Metric
R17: 43K; R_0805_2012Metric
R18, R19: 22R; R_0805_2012Metric
R20: 1K; R_0805_2012Metric
S4: SK12D07VG3NS; Switch_Slide_SK12D07VG3NS; Mouser Part Number 611-SK12D07VG3NS
U1: MP1584EN-LF-Z; SOIC-9_P1.27mm; Mouser Part Number 946-MP1584ENLFZ
U2: USBLC6-2SC6; SOT-23-6
U3: AMS1117 3.3; SOT-223-3_TabPin2

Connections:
+3V3: C10.1, R20.2, U3.2 (VO); also elsewhere on the board
/Power/D+: J6.6 (DP1), J6.8 (DP2), R19.2
/Power/D-: J6.5 (DN2), J6.7 (DN1), R18.2
/Power/DM: U2.6 (I/O1); also elsewhere on the board
/Power/DP: U2.4 (I/O2); also elsewhere on the board
/Power/VBUS_IN: C1.1, C2.1, C3.1, R9.2, S4.2, U1.7 (VIN)
GND: C1.2, C2.2, C3.2, C6.1, C7.2, C8.2, C9.2, C10.2, D1.2 (A), J5.2, J6.1 (GND), J6.12 (GND), LD1.1 (K), R10.2, R11.2, R12.2, R13.1, R14.1, R15.1, R16.1, U1.5 (GND), U1.9 (EP), U2.2 (GND), U3.1 (GND); also elsewhere on the board
unnamed: C4.2, R11.1
unnamed: C9.1, J6.2 (VBUS), J6.11 (VBUS), L2.2
unnamed: C5.2, D1.1 (K), L1.1, U1.1 (SW)
unnamed: J5.1, S4.3
unnamed: J6.4 (CC1), R13.2
unnamed: J6.10 (CC2), R14.2
unnamed: J6.13 (SHIELD), R16.2
unnamed: LD1.2 (A), R20.1
unnamed: R18.1, U2.1 (I/O1)
unnamed: R19.1, U2.3 (I/O2)
unnamed: C5.1, U1.8 (BST)
unnamed: C4.1, U1.3 (COMP)
unnamed: R9.1, R10.1, U1.2 (EN)
unnamed: R15.2, R17.2, U1.4 (FB)
unnamed: R12.1, U1.6 (FREQ)
VBUS: C6.2, C7.1, C8.1, L1.2, L2.1, R17.1, U2.5 (VBUS), U3.3 (VI); also elsewhere on the board

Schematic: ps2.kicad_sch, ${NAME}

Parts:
C11, C12, C13, C14: 100n; C_0805_2012Metric
J7: MDC-036; MiniDIN_6pin_Female
U4: TXS0104EDR; SOIC-14_P1.27mm; Mouser Part Number 595-TXS0104EDR

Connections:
+3V3: C12.1, C13.1, U4.1 (VCCA), U4.8 (OE); also elsewhere on the board
/PGPIO0: U4.4 (A3); also elsewhere on the board
/PGPIO1: U4.5 (A4); also elsewhere on the board
/PGPIO2: U4.2 (A1); also elsewhere on the board
/PGPIO3: U4.3 (A2); also elsewhere on the board
/PS2/KB_CLK_5V: J7.5, U4.13 (B1)
/PS2/KB_DATA_5V: J7.1, U4.12 (B2)
/PS2/MS_CLK_5V: J7.6, U4.11 (B3)
/PS2/MS_DATA_5V: J7.2, U4.10 (B4)
GND: C11.2, C12.2, C13.2, C14.2, J7.3, U4.7 (GND); also elsewhere on the board
VBUS: C11.1, C14.1, J7.4, U4.14 (VCCB); also elsewhere on the board

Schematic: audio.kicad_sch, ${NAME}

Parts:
J13: PAM L; JST_GH_1x02_P1.25mm
J14: PAM R; JST_GH_1x02_P1.25mm
J15: SJ1-3525N; AudioJack_3.5mm_SJ1-3525N; Mouser Part Number 490-SJ1-3525N

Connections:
/Audio/AMP_OUTL: J15.2 (TIP); also elsewhere on the board
/Audio/AMP_OUTR: J15.3 (RING); also elsewhere on the board
/Audio/AMP_PAM_OUTL_M: J13.2; also elsewhere on the board
/Audio/AMP_PAM_OUTL_P: J13.1; also elsewhere on the board
/Audio/AMP_PAM_OUTR_M: J14.2; also elsewhere on the board
/Audio/AMP_PAM_OUTR_P: J14.1; also elsewhere on the board
GND: J15.1 (SLEEVE); also elsewhere on the board

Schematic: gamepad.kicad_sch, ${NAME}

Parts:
D5: 3V3; D_MiniMELF
J16: GP2; DSUB-9_Male_TopMount
R119: 1K; R_0805_2012Metric

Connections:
/PGPIO20: J16.4; also elsewhere on the board
/PGPIO21: J16.3; also elsewhere on the board
/PGPIO26: D5.1 (K), R119.1; also elsewhere on the board
GND: D5.2 (A), J16.8; also elsewhere on the board
unnamed: J16.2, R119.2
VBUS: J16.6; also elsewhere on the board

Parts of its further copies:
D6: 3V3; D_MiniMELF
J17: GP2; DSUB-9_Male_TopMount
R120: 1K; R_0805_2012Metric

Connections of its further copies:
/PGPIO20: J17.4; also elsewhere on the board
/PGPIO21: J17.3; also elsewhere on the board
/PGPIO27: D6.1 (K), R120.1; also elsewhere on the board
GND: D6.2 (A), J17.8; also elsewhere on the board
unnamed: J17.2, R120.2
VBUS: J17.6; also elsewhere on the board

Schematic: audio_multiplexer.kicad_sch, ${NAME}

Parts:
C48: 100n; C_0805_2012Metric
R117, R118: 10K; R_0805_2012Metric
U21: 74HC4052D; SOP-16_P1.27mm; Mouser Part Number 771-74HC4052D-T

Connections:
/Audio Multiplexer/AMP_IN_L: U21.13 (1Z); also elsewhere on the board
/Audio Multiplexer/AMP_IN_R: U21.3 (2Z); also elsewhere on the board
/Audio Multiplexer/PWM_OUT_L: U21.12 (1Y0); also elsewhere on the board
/Audio Multiplexer/PWM_OUT_R: U21.1 (2Y0); also elsewhere on the board
/Audio Multiplexer/SW_TDA: R117.2, U21.10 (S0); also elsewhere on the board
/Audio Multiplexer/SW_TS: R118.2, U21.9 (S1); also elsewhere on the board
/Audio Multiplexer/TDA_L: U21.14 (1Y1); also elsewhere on the board
/Audio Multiplexer/TDA_R: U21.5 (2Y1); also elsewhere on the board
/Audio/TS/L_IN: U21.15 (1Y2); also elsewhere on the board
/Audio/TS/R_IN: U21.2 (2Y2); also elsewhere on the board
GND: C48.1, R117.1, R118.1, U21.4 (2Y3), U21.6 (~E), U21.7 (VEE), U21.8 (GND), U21.11 (1Y3); also elsewhere on the board
VBUS: C48.2, U21.16 (VCC); also elsewhere on the board

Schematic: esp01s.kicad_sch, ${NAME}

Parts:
U16: ESP-01v090; ESP-01S

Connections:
+3V3: U16.7 (VCC); also elsewhere on the board
/ESP01S/CH_PD: U16.3 (CH_PD); also elsewhere on the board
/ESP01S/GPIO0: U16.6 (GPIO0); also elsewhere on the board
/ESP01S/GPIO2: U16.4 (GPIO2); also elsewhere on the board
/ESPRST: U16.5 (RST); also elsewhere on the board
/PGPIO38: U16.8 (URXD); also elsewhere on the board
/PGPIO39: U16.1 (UTXD); also elsewhere on the board
GND: U16.2 (GND); also elsewhere on the board

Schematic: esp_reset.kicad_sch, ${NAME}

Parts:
S7: ESP Reset; Button_SMD_TS1234VW

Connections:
/ESPRST: S7.1; also elsewhere on the board
GND: S7.2, S7.3 (GND); also elsewhere on the board

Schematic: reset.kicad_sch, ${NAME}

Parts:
S5: RP Reset; Button_SMD_3x4x2mm; Mouser Part Number 611-KMR221G-LFS
S6: RP Reset; Button_SMD_TS1234VW

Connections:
/PRUN: S5.1, S5.3, S6.1; also elsewhere on the board
GND: S5.2, S5.4, S6.2, S6.3 (GND); also elsewhere on the board

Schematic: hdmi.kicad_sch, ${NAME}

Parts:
C24: 100n; C_0805_2012Metric
D4: 1N5819WS; D_SOD-323
J9: DC3RX19JA2; HDMI_Female
R63, R64, R65, R66, R67, R68, R69, R70: 270R; R_0805_2012Metric

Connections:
/PGPIO12: R65.2; also elsewhere on the board
/PGPIO13: R69.2; also elsewhere on the board
/PGPIO14: R63.2; also elsewhere on the board
/PGPIO15: R66.2; also elsewhere on the board
/PGPIO16: R67.2; also elsewhere on the board
/PGPIO17: R70.2; also elsewhere on the board
/PGPIO18: R64.2; also elsewhere on the board
/PGPIO19: R68.2; also elsewhere on the board
GND: C24.2, J9.2 (G_D2), J9.5 (G_D1), J9.8 (G_D0), J9.11 (G_CLK), J9.17 (G_DDC/CEC), J9.20 (SHIELD1), J9.21 (SHIELD2), J9.22 (SHIELD3), J9.23 (SHIELD4); also elsewhere on the board
unnamed: C24.1, D4.1 (K), J9.18 (+5V)
unnamed: J9.12 (CLKN), R65.1
unnamed: J9.10 (CLKP), R69.1
unnamed: J9.9 (D0N), R63.1
unnamed: J9.7 (D0P), R66.1
unnamed: J9.6 (D1N), R67.1
unnamed: J9.4 (D1P), R70.1
unnamed: J9.3 (D2N), R64.1
unnamed: J9.1 (D2P), R68.1
VBUS: D4.2 (A); also elsewhere on the board

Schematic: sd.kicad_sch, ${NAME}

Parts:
C49: 100n; C_0805_2012Metric
J18: 104031-0811; MicroSD_SMD_Long

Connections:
+3V3: C49.2, J18.4 (VDD); also elsewhere on the board
/PGPIO4: J18.7 (DAT0); also elsewhere on the board
/PGPIO5: J18.2 (DAT3/CD); also elsewhere on the board
/PGPIO6: J18.5 (CLK); also elsewhere on the board
/PGPIO7: J18.3 (CMD); also elsewhere on the board
GND: C49.1, J18.6 (VSS), J18.SH (SHIELD); also elsewhere on the board

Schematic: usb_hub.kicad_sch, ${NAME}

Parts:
C26: 4.7u; C_0805_2012Metric; LCSC C1746
U13: MW7211A; SOP-16_P1.27mm

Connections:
/USB Hub/DM1: U13.7 (DM3); also elsewhere on the board
/USB Hub/DM2: U13.5 (DM2); also elsewhere on the board
/USB Hub/DM3: U13.3 (DM1); also elsewhere on the board
/USB Hub/DM4: U13.1 (DM0); also elsewhere on the board
/USB Hub/DM_IN: U13.10 (DMU); also elsewhere on the board
/USB Hub/DP1: U13.8 (DP3); also elsewhere on the board
/USB Hub/DP2: U13.6 (DP2); also elsewhere on the board
/USB Hub/DP3: U13.4 (DP1); also elsewhere on the board
/USB Hub/DP4: U13.2 (DP0); also elsewhere on the board
/USB Hub/DP_IN: U13.11 (DPU); also elsewhere on the board
GND: C26.2, U13.15 (GND), U13.16 (GND); also elsewhere on the board
unnamed: U13.12 (VD33), U13.14 (VD3)
VBUS: C26.1, U13.13 (VDD5); also elsewhere on the board

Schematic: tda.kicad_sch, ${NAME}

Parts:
C33, C35: 10u; C_0805_2012Metric
C34: 100n; C_0805_2012Metric
R98: 100R; R_0805_2012Metric
R99, R100: 470R; R_0805_2012Metric
U18: TDA1387T; SO-8

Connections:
/Audio Multiplexer/TDA_L: R100.2, U18.6 (A_LEFT); also elsewhere on the board
/Audio Multiplexer/TDA_R: R99.1, U18.8 (A_RIGHT); also elsewhere on the board
/PGPIO9: U18.3 (DATA); also elsewhere on the board
/PGPIO10: U18.1 (SCLK); also elsewhere on the board
/PGPIO11: U18.2 (LRCK); also elsewhere on the board
GND: C33.2, C34.2, C35.2, R99.2, R100.1, U18.4 (AGND); also elsewhere on the board
unnamed: C35.1, U18.7 (FLT)
unnamed: C33.1, C34.1, R98.1, U18.5 (VA)
VBUS: R98.2; also elsewhere on the board

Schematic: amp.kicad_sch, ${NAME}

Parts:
C36, C41, C46: 1u; C_0805_2012Metric
C37, C38, C39, C43, C44: 10u; C_0805_2012Metric
C40, C45: 100n; C_0805_2012Metric
C42: 10u; CP_Radial_D4.0mm_P1.50mm
C47: 100u; C_Radial_D6.3mm_P2.50mm
R101, R102, R103, R104, R105, R106, R107, R108, R109, R112, R116: 10K; R_0805_2012Metric
R110, R111: 47K; R_0805_2012Metric
R113: 100R; R_0805_2012Metric
R114, R115: 20K; R_0805_2012Metric
U19: PAM8403D; SOP-16_P1.27mm; Mouser Part Number 700-MAX232CSE
U20: LM358; SO-8

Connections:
/Audio Multiplexer/AMP_IN_L: C37.1, R102.1; also elsewhere on the board
/Audio Multiplexer/AMP_IN_R: C38.1, R104.1; also elsewhere on the board
/Audio/AMP_OUTL: C43.2, R114.2; also elsewhere on the board
/Audio/AMP_OUTR: C44.2, R115.2; also elsewhere on the board
/Audio/AMP_PAM_OUTL_M: U19.3 (-OUTL); also elsewhere on the board
/Audio/AMP_PAM_OUTL_P: U19.1 (+OUT_L); also elsewhere on the board
/Audio/AMP_PAM_OUTR_M: U19.14 (-OUT_R); also elsewhere on the board
/Audio/AMP_PAM_OUTR_P: U19.16 (+OUT_R); also elsewhere on the board
/MONO_L: C36.1, R101.1, R102.2; also elsewhere on the board
/MONO_R: C41.1, R103.1, R104.2; also elsewhere on the board
/SHND: R116.2, U19.12 (SHND); also elsewhere on the board
GND: C39.1, C40.2, C42.2, C45.1, C46.2, C47.2, R101.2, R103.2, R106.1, R114.1, R115.1, U19.2 (PGND), U19.11 (GND), U19.15 (PGND), U20.4 (V-); also elsewhere on the board
unnamed: C36.2, R107.2
unnamed: C37.2, R108.2
unnamed: C38.2, R109.2
unnamed: C41.2, R112.2
unnamed: C43.1, R110.1, U20.7
unnamed: C44.1, R111.1, U20.1
unnamed: R107.1, U19.7 (INL)
unnamed: R112.1, U19.10 (INR)
unnamed: C40.1, U19.8 (VREF)
unnamed: C39.2, R105.1, R106.2, U20.3 (+), U20.5 (+)
unnamed: R109.1, R111.2, U20.2 (-)
unnamed: R108.1, R110.2, U20.6 (-)
unnamed: C42.1, C45.2, R105.2, R113.2, U20.8 (V+)
VBUS: C46.1, C47.1, R113.1, R116.1, U19.4 (PVDD), U19.5 (MUTE), U19.6 (VDD), U19.13 (PVDD); also elsewhere on the board

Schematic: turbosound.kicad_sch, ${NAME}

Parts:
C15, C16: 22p; C_0805_2012Metric
C17, C19: 100u; C_Radial_D6.3mm_P2.50mm
C18, C20, C21, C22: 100n; C_0805_2012Metric
D2, D3: 1N4148; D_SOD-323
LD2, LD3: Orange; LED_0805
Q1: BC850; SOT-23
R21, R23, R28, R36, R37: 1K; R_0805_2012Metric
R22: 100K; R_0805_2012Metric
R24, R25, R38, R39: 4.7K; R_0805_2012Metric
R26, R27, R40, R41: 2K; R_0805_2012Metric
R29, R30, R31, R32, R33, R34, R35, R44, R46, R49, R51, R53, R56, R58: 10K; R_0805_2012Metric
R42, R43, R45, R48, R50, R52, R54, R57, R59: 20K; R_0805_2012Metric
R47, R55: 120R; R_0805_2012Metric
S8: TS Reset; Button_SMD_3x4x2mm; Mouser Part Number 611-KMR221G-LFS
U5, U7: JFC95101; DIP-40_W15.24mm_Socket
U6: 74HC74; SOIC-14_P1.27mm
U8, U9: 74HC595; SOP-16_P1.27mm
X1: 3.58 MHz; Crystal_HC49-S

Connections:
/Audio/TS/A1: R26.2, U5.4 (B)
/Audio/TS/A2: R40.2, U7.4 (B)
/Audio/TS/B1: R24.2, R25.2, U5.3 (A)
/Audio/TS/B2: R38.2, R39.2, U7.3 (A)
/Audio/TS/BEEP: R32.2, R33.2, U9.4 (QE)
/Audio/TS/C1: R27.2, U5.38 (C)
/Audio/TS/C2: R41.2, U7.38 (C)
/Audio/TS/CLK_1.75M: U5.22 (CLOCK), U6.5 (Q), U7.22 (CLOCK)
/Audio/TS/COVOX_OUT: R30.2, R31.2, R58.2, R59.1
/Audio/TS/DA0: U5.37 (DA0), U7.37 (DA0), U8.15 (QA)
/Audio/TS/DA1: U5.36 (DA1), U7.36 (DA1), U8.1 (QB)
/Audio/TS/DA2: U5.35 (DA2), U7.35 (DA2), U8.2 (QC)
/Audio/TS/DA3: U5.34 (DA3), U7.34 (DA3), U8.3 (QD)
/Audio/TS/DA4: U5.33 (DA4), U7.33 (DA4), U8.4 (QE)
/Audio/TS/DA5: U5.32 (DA5), U7.32 (DA5), U8.5 (QF)
/Audio/TS/DA6: U5.31 (DA6), U7.31 (DA6), U8.6 (QG)
/Audio/TS/DA7: U5.30 (DA7), U7.30 (DA7), U8.7 (QH)
/Audio/TS/DAC0: R43.2, U7.13 (IOB0)
/Audio/TS/DAC1: R45.2, U7.12 (IOB1)
/Audio/TS/DAC2: R48.2, U7.11 (IOB2)
/Audio/TS/DAC3: R50.2, U7.10 (IOB3)
/Audio/TS/DAC4: R52.2, U7.9 (IOB4)
/Audio/TS/DAC5: R54.2, U7.8 (IOB5)
/Audio/TS/DAC6: R57.2, U7.7 (IOB6)
/Audio/TS/DAC7: R59.2, U7.6 (IOB7)
/Audio/TS/L_IN: R25.1, R26.1, R31.1, R33.1, R35.1, R39.1, R40.1, R47.1; also elsewhere on the board
/Audio/TS/R_IN: R24.1, R27.1, R30.1, R32.1, R34.1, R38.1, R41.1, R55.1; also elsewhere on the board
/Audio/TS/SAVE: R34.2, R35.2, U9.5 (QF)
/Audio/TS/YM_BC1: U5.29 (BC1), U7.29 (BC1), U9.15 (QA)
/Audio/TS/YM_BDIR: U5.27 (BDIR), U7.27 (BDIR), U9.1 (QB)
/Audio/TS/YM_CS1: LD2.2 (A), U5.25 (A8), U9.2 (QC)
/Audio/TS/YM_CS2: LD3.2 (A), U7.25 (A8), U9.3 (QD)
/Audio/TS/YM_RST: D2.2 (A), D3.2 (A), R29.1, U5.23 (~RESET), U7.23 (~RESET)
/Audio/TS/YM_SEL1: R21.2, U5.26 (~SEL)
/Audio/TS/YM_SEL2: R28.2, U7.26 (~SEL)
/PGPIO9: U8.12 (RCLK), U9.12 (RCLK); also elsewhere on the board
/PGPIO10: U8.11 (SRCLK), U9.11 (SRCLK); also elsewhere on the board
/PGPIO11: U8.14 (SER); also elsewhere on the board
GND: C15.1, C16.1, C17.2, C18.2, C19.2, C20.2, C21.2, C22.2, Q1.2 (E), R36.1, R37.1, R42.1, R47.2, R55.2, S8.2, S8.4, U5.1 (VSS), U5.24 (~A9), U6.7 (GND), U7.1 (VSS), U7.24 (~A9), U8.8 (GND), U8.13 (~OE), U9.8 (GND), U9.13 (~OE); also elsewhere on the board
unnamed: D2.1 (K), S8.1, S8.3
unnamed: D3.1 (K), U9.6 (QG)
unnamed: LD2.1 (K), R36.2
unnamed: LD3.1 (K), R37.2
unnamed: C15.2, Q1.1 (B), R22.1, X1.1
unnamed: C16.2, Q1.3 (C), R22.2, R23.1, U6.3 (C), X1.2
unnamed: R42.2, R43.1, R44.1
unnamed: R44.2, R45.1, R46.1
unnamed: R46.2, R48.1, R49.1
unnamed: R49.2, R50.1, R51.1
unnamed: R51.2, R52.1, R53.1
unnamed: R53.2, R54.1, R56.1
unnamed: R56.2, R57.1, R58.1
unnamed: U6.2 (D), U6.6 (~Q)
unnamed: U8.9 (QH'), U9.14 (SER)
VBUS: C17.1, C18.1, C19.1, C20.1, C21.1, C22.1, R21.1, R23.2, R28.1, R29.2, U5.28 (BC2), U5.40 (VCC), U6.1 (~R), U6.4 (~S), U6.14 (VCC), U7.28 (BC2), U7.40 (VCC), U8.10 (~SRCLR), U8.16 (VCC), U9.10 (~SRCLR), U9.16 (VCC); also elsewhere on the board

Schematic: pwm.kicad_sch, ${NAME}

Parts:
C31, C32: 47n; C_0805_2012Metric
R90, R92: 10K; R_0805_2012Metric
R91, R93, R94, R95: 2K; R_0805_2012Metric
R96, R97: 1K; R_0805_2012Metric

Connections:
/Audio Multiplexer/PWM_OUT_L: R92.2, R93.1; also elsewhere on the board
/Audio Multiplexer/PWM_OUT_R: R90.2, R91.1; also elsewhere on the board
/PGPIO9: R94.1, R95.1; also elsewhere on the board
/PGPIO10: R97.2; also elsewhere on the board
/PGPIO11: R96.2; also elsewhere on the board
GND: C31.2, C32.2, R91.2, R93.2; also elsewhere on the board
unnamed: C31.1, R90.1, R94.2, R97.1
unnamed: C32.1, R92.1, R95.2, R96.1

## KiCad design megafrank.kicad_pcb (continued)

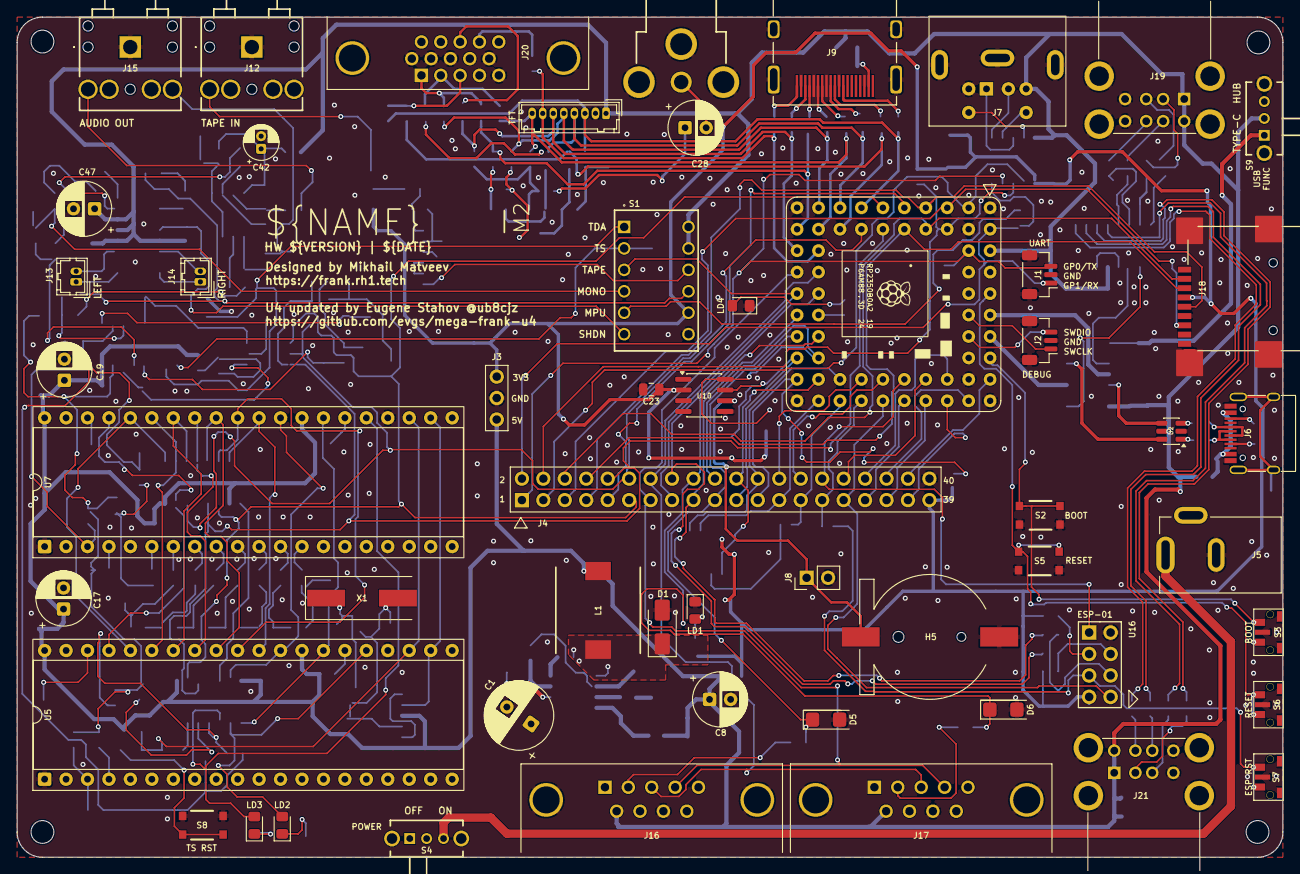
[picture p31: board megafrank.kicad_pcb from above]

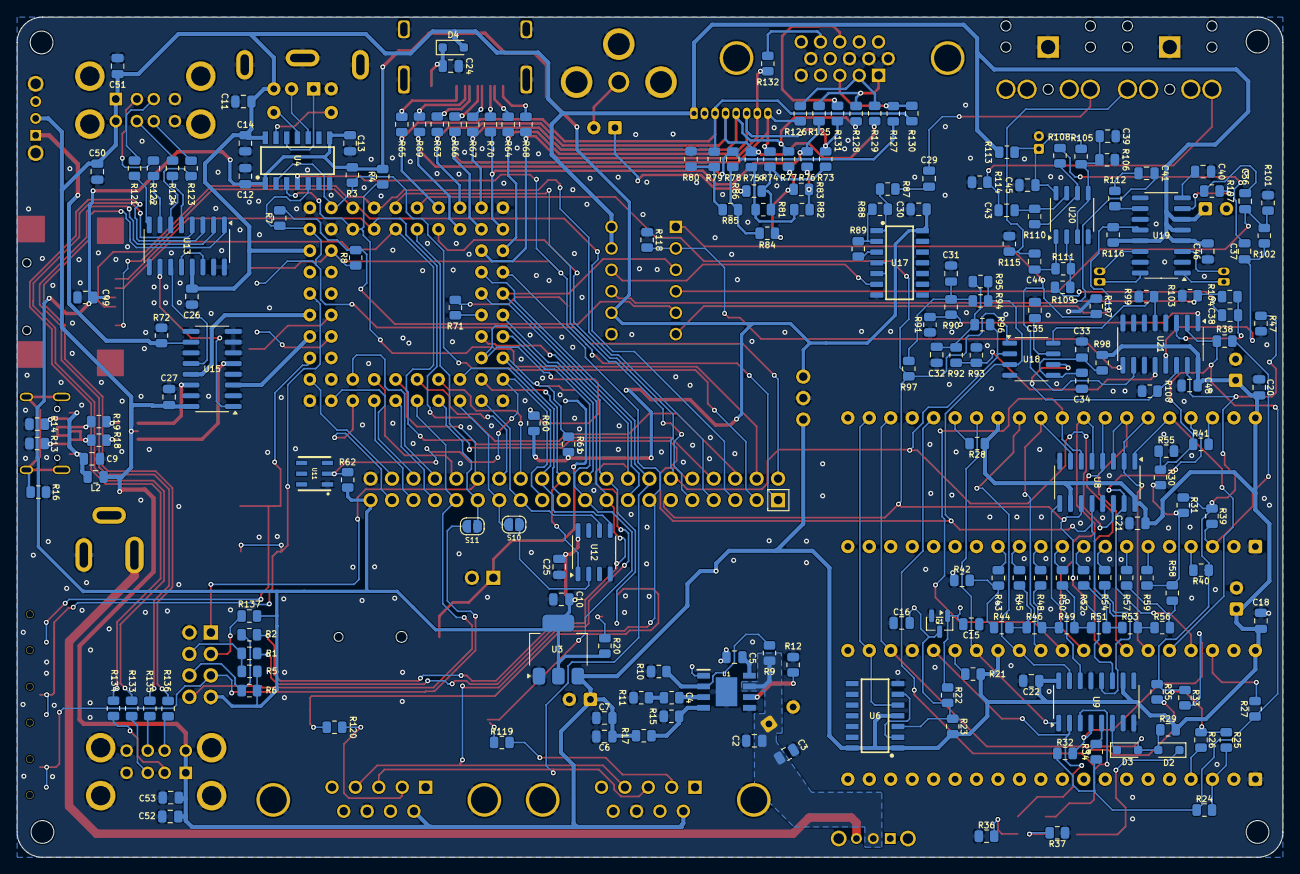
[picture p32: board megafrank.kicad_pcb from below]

Board: 2 copper layers, 149.9 x 99.5 mm, 262 parts (204 on the bottom side), 223 nets.

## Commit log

2026-07-08 add 3d/*
    [AudioJack_3.5mm_PJ320D.step, AudioJack_3.5mm_PJ320D_AudioOut.step, AudioJack_3.5mm_PJ320D_TapeIn.step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]
2026-07-08 add schematics
    [amp.kicad_sch, audio.kicad_sch, audio_multiplexer.kicad_sch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]
2026-07-08 add pcb
    [megafrank.kicad_pcb]
2026-07-08 add old docs and gerbers
2026-07-08 add docs and gerbers for megafrank version 1.02-u4
2026-07-08 add case folder stub
2026-07-08 add board view image
2026-07-21 update silkscreen and vias
    [megafrank.kicad_pcb]
2026-07-21 add gerbers
    [megafrank-B_Cu.gbr, megafrank-B_Mask.gbr, megafrank-B_Paste.gbr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]
2026-07-21 update packed gerbers for production
2026-07-21 add minimalistic topless case
    [bottom_only.FCStd, bottom_only.step, bottom_only.stl]
2026-07-21 update board view
2026-07-21 update bom
2026-07-21 update bom and assembly
2026-07-21 refresh gerbers
    [megafrank-B_Cu.gbr, megafrank-B_Mask.gbr, megafrank-B_Paste.gbr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]
2026-07-21 change output dir for gerbers
    [megafrank.kicad_pcb]
2026-07-21 Clarify DIP switches
2026-08-11 Add case for 1_02u4
    [bottom.step, bottom.stl, top-m2.5-inserts32.step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]

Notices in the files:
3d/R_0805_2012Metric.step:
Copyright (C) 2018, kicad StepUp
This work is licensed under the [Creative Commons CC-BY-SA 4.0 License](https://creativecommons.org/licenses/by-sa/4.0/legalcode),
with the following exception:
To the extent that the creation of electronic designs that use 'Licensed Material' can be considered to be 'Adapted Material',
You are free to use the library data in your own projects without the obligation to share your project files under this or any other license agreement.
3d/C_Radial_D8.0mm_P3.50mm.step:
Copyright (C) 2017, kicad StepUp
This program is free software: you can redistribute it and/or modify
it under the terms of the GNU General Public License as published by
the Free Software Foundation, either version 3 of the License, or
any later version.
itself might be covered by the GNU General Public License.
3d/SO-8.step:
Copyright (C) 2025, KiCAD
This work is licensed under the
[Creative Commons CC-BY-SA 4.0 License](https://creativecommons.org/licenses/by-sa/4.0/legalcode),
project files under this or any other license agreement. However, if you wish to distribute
